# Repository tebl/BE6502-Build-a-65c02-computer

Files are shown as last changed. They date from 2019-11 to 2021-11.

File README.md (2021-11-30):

# BE6502 - Build a 6502 computer
[Ben Eater](https://eater.net/) has been a huge inspiration for many getting into building computers using basic electronic building blocks, his [videos](https://www.youtube.com/user/eaterbc) are truly excellent and it is no wonder he's often referred to as the Bob Ross of Breadboards! His latest project is [building a 6502 computer](https://eater.net/6502) on a breadboard, a video series that at this moment in time still has not concluded so this may not match whatever he does after part 7!

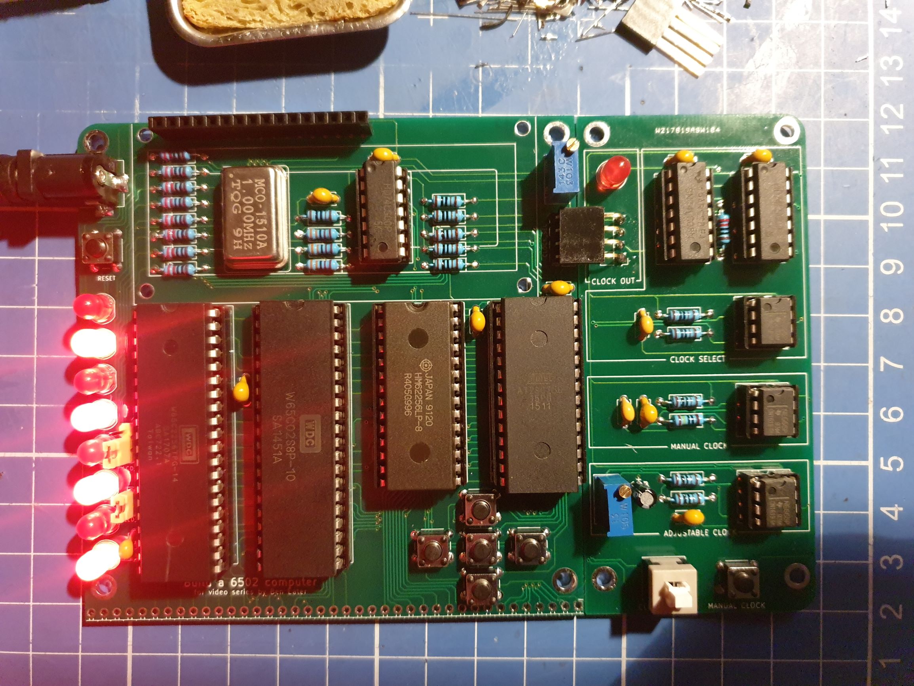
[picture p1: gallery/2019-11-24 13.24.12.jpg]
SBC and clock module


Personally, I am somewhat awful at getting things to work on breadboards - even when buying the good stuff from reputable electronics shops, so I usually just go directly to PCB instead. I've designed a few other amateur projects using the trusty old 6502-processor before, but this'll be the first one to be tackled with the more modern Western Designs CPU (W65C02) instead. His video series depends this specific brand of CPU, this is due to the way it is run using a slow and sometimes completely halted clock that wouldn't work the same on other brands. The older 6502 variants will more than likely loose their context, with the end result being a CPU doing unexpected things instead of running as the machine code would normally dictate. 

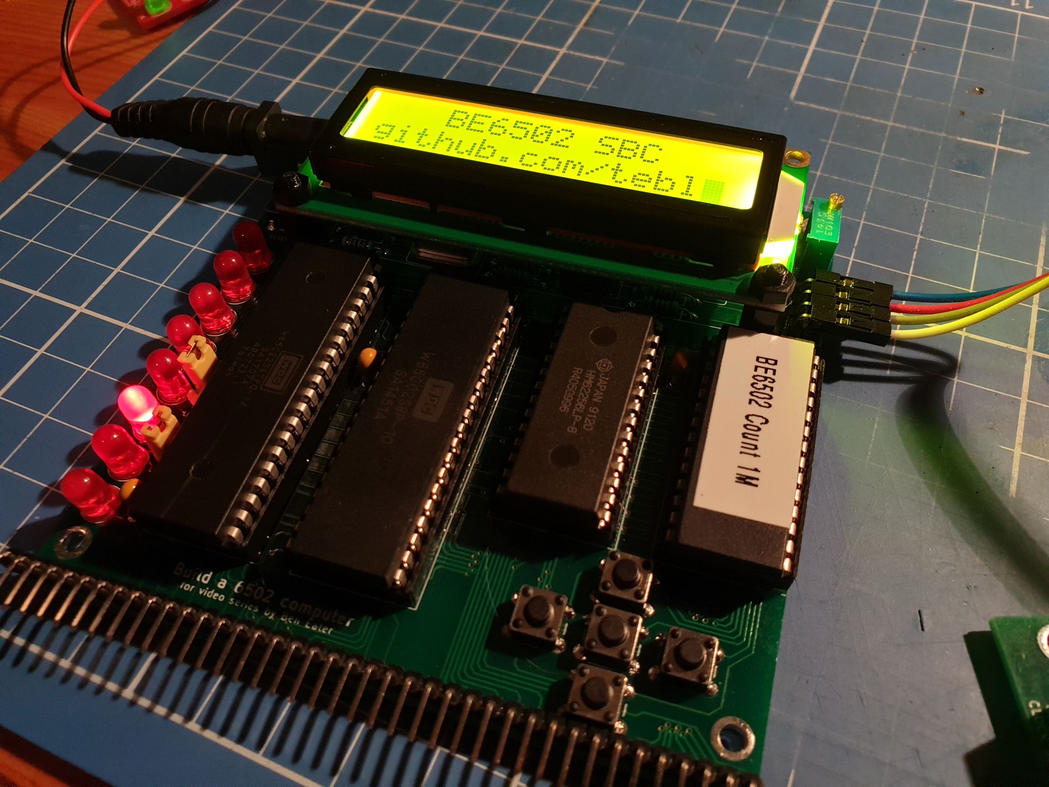
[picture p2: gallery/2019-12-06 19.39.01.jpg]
LCD mounted

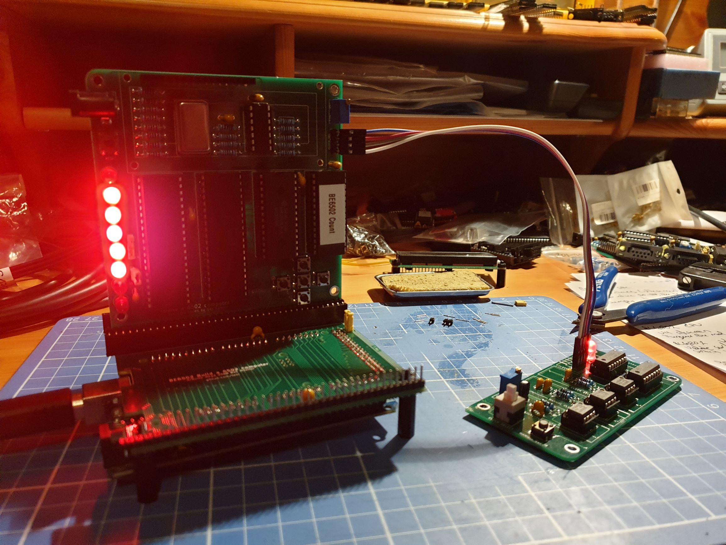
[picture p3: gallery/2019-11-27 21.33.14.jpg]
Computer with backplane


The BE6502 computer has a 39-pin backplane connector, like most of my other projects and these can be used to connect to an Arduino Mega as in the videos, a logic probe or even a separate larger backplane if you intend to build any more additional expansions for use with the computer. The picture above shows the SBC along with clock and Arduino Mega Shield. See *System modules* below for a listing of available modules, which are required at the various steps in the video series and any optional extras I felt like listing that would be compatible with the supplied boards.

Over time I may even add some short videos to show off the computer in action, but given that I have a voice suited for silent movies they'll probably just be videos of the computer blinking away by itself. As they become available, you'll find those on this [Youtube-playlist](https://www.youtube.com/playlist?list=PLOJSxpeHB9KTk9ptKCbEZnNEy9QRU02SS).

## Project status
The BE6502 computer is still in the prototyping stage and though I have studied the videos up to this point, at the time of writing that'd be everything up to and including part 7. See [TODO](https://github.com/tebl/BE6502/blob/master/TODO.md) for an overview of things I've yet to implement or want to change in the future!

Some of these details are likely to change as his original design by itself does not seem to reset reliably when using the 1 Mhz clock. At the moment I've got it fixed by using one of my own RC6502-modules in one of the backplane slots, details for this module can be found at https://github.com/tebl/RC6502-Apple-1-Replica/tree/master/RC6502%20Reset%20Circuit. If you'd like to build it up on a breadboard you can easily do that, I've installed pin headers as the front slot of my backplane to make it easier to do things like that. Alternatively you could program the Arduino Mega to do it for you!

### Errata
* [BE6502 SBC](https://github.com/tebl/BE6502/tree/master/BE6502%20SBC) revision A boards are missing a pull-up on the BE-pin - refer to this [picture](https://github.com/tebl/BE6502-Build-a-65c02-computer/raw/master/gallery/2020-02-16%2015.50.14-1.jpg) for a convenient spot to add one. This is resistor R18 in the current version of the schematic.
* [BE6502 Clock](https://github.com/tebl/BE6502-Build-a-65c02-computer/tree/master/BE6502%20Clock) module revision B had C8 shorted, refer to this [picture](https://github.com/tebl/BE6502-Build-a-65c02-computer/blob/master/gallery/Screenshot%202021-11-30%20194604.png) for how it should have looked (tracks have not been moved). In order to fix an existing PCB, cut off C8 and cut the trace directly below it. Installing new C8 (100nF) can be done on the back of the board, either across the short side of SW1 or between U2 pins 1 and 2.

## System modules
The following listed modules are available for use with the computer, where available I've also added an order URL to a shared project on PCBway for ease of ordering - click the module name to get more information as well as a complete list of components needed to build it (usually referred to as a BOM). Some modules have been marked with other computer names, these are other modules that I've found works directly and can be of interest when playing around with the BE6502-computer.

| Name | Video series, parts 1-7 | Future expansions | Order  |
| --- | --- | --- | --- |
| [Computer (SBC)](https://github.com/tebl/BE6502/tree/master/BE6502%20SBC) | required | | [PCBway](https://www.pcbway.com/project/shareproject/BE6502_Build_a_6502_computer__SBC_module_revision_A_.html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) |
| [Adjustable and manual clock](https://github.com/tebl/BE6502/tree/master/BE6502%20Clock) | required | | [PCBway](https://www.pcbway.com/project/shareproject/BE6502_Build_a_6502_computer__Clock_module_revision_A_.html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) |
| [Arduino Mega Shield and Backplane ](https://github.com/tebl/BE6502/tree/master/BE6502%20Mega%20Adapter) | required | | [PCBway](https://www.pcbway.com/project/shareproject/BE6502_Build_a_6502_computer__Arduino__and_backplane_module_.html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) |
| [RC6502 Backplane](https://github.com/tebl/RC6502-Apple-1-Replica/tree/master/RC6502%20Backplane) |  | optional | [PCBWay](https://www.pcbway.com/project/shareproject/RC6502_Apple_1_Replica__Backplane_module_revision_A_.html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) |
| [RC6502 Prototyping module](https://github.com/tebl/RC6502-Apple-1-Replica/tree/master/RC6502%20Prototyping) | | optional | [PCBWay](https://www.pcbway.com/project/shareproject/RC6502_Apple_1_Replica__Module_prototyping_board_.html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) |

If you would like to have a copy of one or more modules (usually 5$ per module), consider using the order links in order to support the development of these boards while doing so. You can alternatively zip up the contents of the export directory for each module and give that to your favourite PCB fabrication plant instead if you want to, but note that the files online here may be newer and have changes made to them that may not have been tested yet (the order link above will point to my last tested version).

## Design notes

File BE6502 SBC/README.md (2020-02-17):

# BE6502
[Ben Eater](https://eater.net/) has been a huge inspiration for many getting into building computers using basic electronic building blocks, his [videos](https://www.youtube.com/user/eaterbc) are truly excellent and it is no wonder he's often referred to as the Bob Ross of Breadboards! His latest project is [building a 6502 computer](https://eater.net/6502) on a breadboard, a video series that I'm sure will also inspire a lot of new users to the art of building stuff with the 6502! Check out the main [README](https://github.com/tebl/BE6502) for an overview of all the modules available to the BE6502 computer.

## Computer (SBC-module)
This module specifically contains all of the modules that makes the BE6502 an actual computer, it has the CPU, RAM, ROM and a way of interacting with the world using the VIA-chip. Also described as an SBC-module which means that it is a *Single Board Computer* though I'm certainly a fan of building more things around it, I just look at it has giving the computer more tricks that it can use to both entertain and educate us at the same time.

SBC and clock module

The picture above shows an assembled and currently running version of the SBC-module (without LCD attached), here I used a female pin header so that the clock module could be slotted directly into place alongside it. I did however change this to use dupont-cables later, this was because the boards separated too easily without having a plate to screw everything into at the moment

As you can see from the big shiny thing, I've also got the 1 Mhz oscillator installed as it is listed in Ben Eaters design though it is not connected by default so that the adjustable or manual clock can be used instead - to enable the 1 Mhz clock you'll need to install a jumper as shown below.

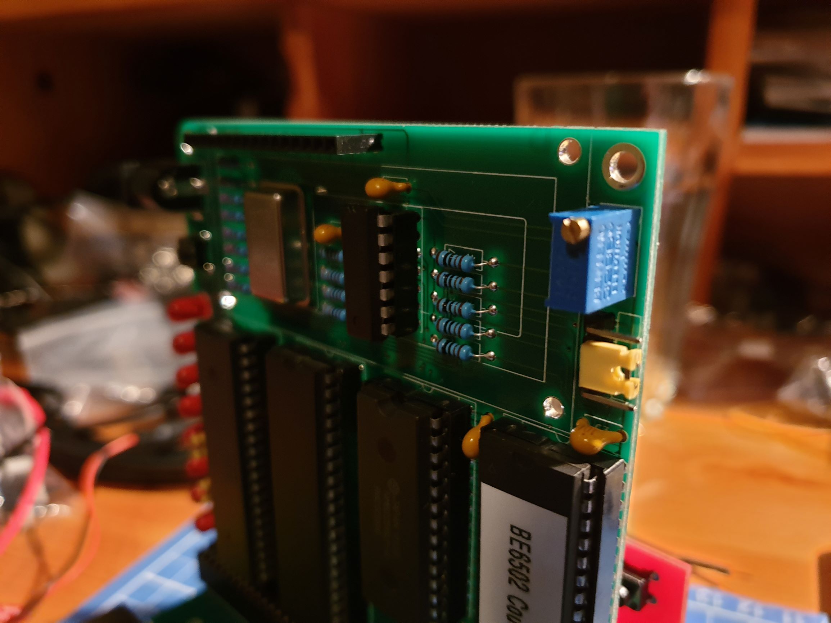
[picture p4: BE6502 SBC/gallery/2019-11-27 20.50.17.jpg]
1 Mhz


I did however have some issues running the CPU reliably at this speed, this is due to the reset circuit specified not being suitable for use at anything other than very low speeds. While we're probably waiting for part 8 of the video series to fix this issue, you can build one yourself on a breadboard with just about the same parts seen earlier in the series.

The hardware solution I'm using is a somewhat simplified version of the one at [RC6502 Reset Circuit](https://github.com/tebl/RC6502-Apple-1-Replica/tree/master/RC6502%20Reset%20Circuit), this is mainly by leaving out the oscillator (since we've already got one) and the 74LS74. For masters of the Commodore 64 the circuit will seem familiar, this is because it's the one originally used on its boards! Alternatively as a software solution, the Arduino Mega can also be used to perform this task - this is done by holding down the first switch (since revision B of the Mega Adapter) or by typing in reset via the serial interface.

## Jumpers
| Reference | Position | Description |
| --- | --- | --- |
| LCD_EN | 1-2 | Enable LCD |
| | 2-3 * | Disable LCD without physically removing it |
| LED_EN | o-o * | Jumpered to enable port B LEDs |
| CLOCK_SEL | 1 ** | VCC |
| | 2-3 ** | Jumper to enable 1 Mhz clock |
| | 4 ** | GND |

*) Marks the default jumpered positions when performing tasks associated with the first parts of the video series. Later, when the LCD is introduced, these will have to be changed.

**) CLOCK_SEL is also used as a connector when connecting the clock module, the pins are made to directly match the 4 positions on both modules. Pins 2-3 should only be jumpered when using 1Mhz clock, but you can also use pins 1 and 4 when powering other circuits. 

# Schematic
The supplied KiCad files should be sufficient as both a schematic and as a starting point for ordering PCBs (basically you could just zip the contents of the export folder and upload that on a fabrication site), the schematic is also available in [PDF-format](https://github.com/tebl/BE6502/raw/master/BE6502%20SBC/export/BE6502%20SBC.pdf) so that you can refer to it while troubleshooting. You could even print it out and hang it on your office wall, excellent conversation starter at any technology-oriented business worth working at (or so I keep telling myself)!

# BOM
This is the part list as it stands now, most should be easy to get a hold of from your local electronic component shop though you might have to consider other sources as that would depend on the quality of your local vendor.

Some vendors will have the same ICs in different form factors, the ones you want will often be specified as being in the form of a DIP/PDIP package. Usually you'll want sockets for each of the ICs as well, a bag of assorted sockets should be easily available without setting you back more than a couple bucks. With the sockets in place, you don't need to dread having to remove an IC later, this leads to easier fault finding and you can easily "borrow" them for other projects later! For the pin headers; you probably won't find the exact pin count as most are meant to be cut down to size, so just buy the 40 pin versions and snip off the parts you don't need!

| Reference | Item | Count |
| --- | --- | ----- |
| PCB | Fabricate yourself using Gerber files | 1 |
| C1-C6 | 100nF ceramic capacitor | 6 |
| D1-D8 | 5mm LED diode, green or red color | 8 |
| J1 | 39p right angle pin header | 1 |
| J2 | 4p right angle pin header | 1 |
| JP1 | 2p straight pin header | 1 |
| JP3 | 3p straight pin header | 1 |
| J3 | 2.1mm x 5.5mm barrel plug | 1 |
| JP1 | Single row, 2p straight pin header | 2 |
| R1-R3,R18* | 3k3 (3300) ohm resistor | 4 |
| R4-R9 | 1k ohm resistor | 6 |
| R10-R17 | 220 ohm resistor | 8 |
| U1 | W65C02 DIP-40 | 1 |
| U2 | 62256 Static RAM (DIP-28) | 1 |
| U3 | 28C256 EEPROM (DIP-28) | 1 |
| U4 | W65C22S DIP-40 | 1 |
| U5 | 74HC00 DIP | 1 |
| U6 | RC1602A, 16x2 character LCD | 1 |
| SW1-SW6 | Momentary push button | 6 |
| X1 | 1.000Mhz TTL Oscillator, (DIP-14) | 1 |
| | Jumpers for settings (CAP headers) | 3 |

*) R18 was added to SBC revision B boards as I had forgotten to add the pull-up for the BE-line, causing instability on the boards due to it floating around. Refer to this [picture](https://github.com/tebl/BE6502-Build-a-65c02-computer/raw/master/gallery/2020-02-16%2015.50.14-1.jpg) for a convenient spot to add it to revision A boards.

When constructing the board I recommend using 60/40 solder as the lead-free is more trouble than it's worth for hobby use, take your time with it and try to build up the board starting with the lowest components before moving on to the larger pieces. The LCD will be mounted on top of other components, so check that nothing shorts on the underside and unless you're 100% sure about the construction and my design - install some female header pins on it so that you can easily remove it while troubleshooting the circuit underneath!

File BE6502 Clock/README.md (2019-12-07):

[Ben Eater](https://eater.net/) has been a huge inspiration for many getting into building computers using basic electronic building blocks, his [videos](https://www.youtube.com/user/eaterbc) are truly excellent and it is no wonder he's often referred to as the Bob Ross of Breadboards! His latest project is [building a 6502 computer](https://eater.net/6502) on a breadboard, a video series that I'm sure will also inspire a lot of new users to the art of building stuff with the 6502! Check out the main [README](https://github.com/tebl/BE6502) for an overview of all the modules available to the BE6502 computer.

## Clock Module
Ben Eater has used the clock module from his 8 bit computer build with this project as well, this module is my implementation with only a few tweaks to the design. The main change apart from the whole PCB-design is that it has a slightly reduced chip-count, this was done by replacing the single used OR-gate with three NAND-gates instead (a little NAND-logic exercise).

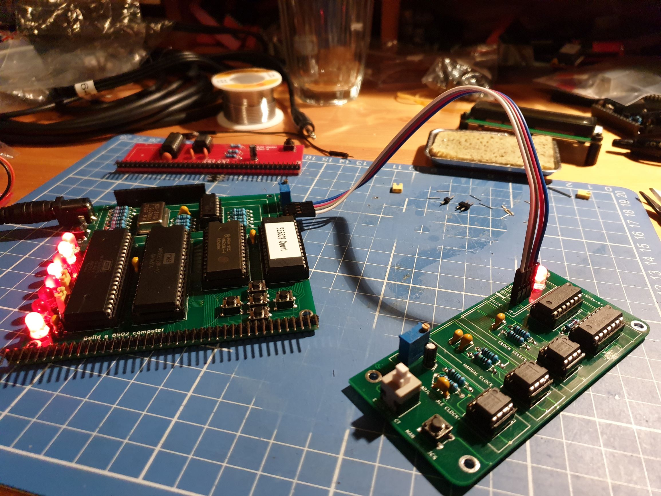
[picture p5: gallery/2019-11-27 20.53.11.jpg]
Running light without overbyte


Like the original breadboard version, you have a manual clock that allows you to clock in manual clock-pulses by pushing the button - the 555 in this case is used for debouncing (mechanical switches are not actually all that consistent). An adjustable slow clock is also available, here the 555 is used as a vibrator and will generate clock pulses with a frequency that is adjustable via the potentiometer. The final 555 allows for a clean transition between the two clocks so you can switch between the two without any erratic bahavior.

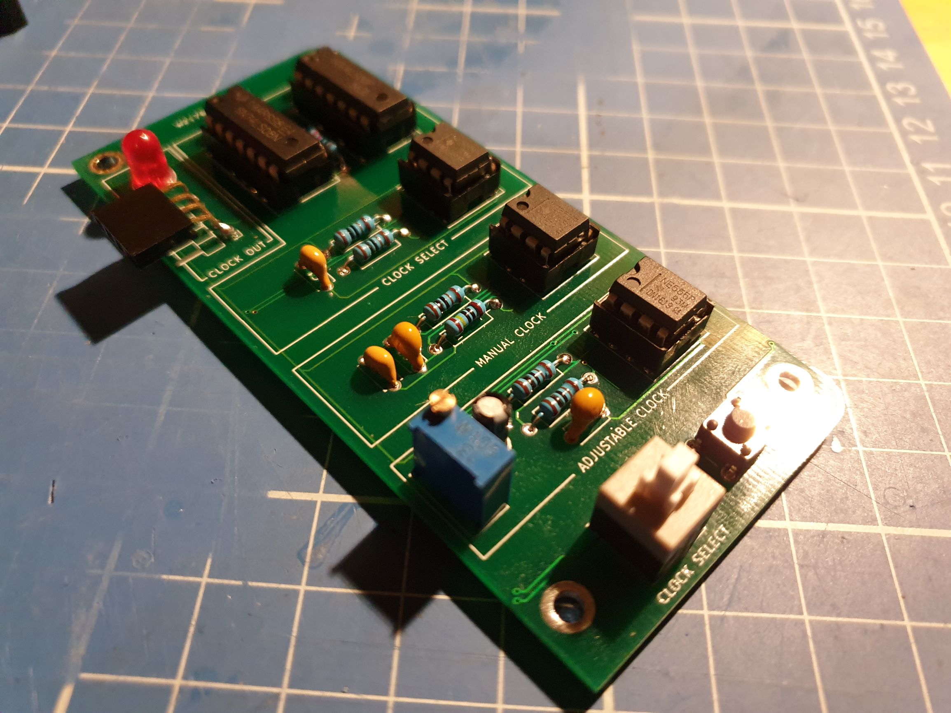
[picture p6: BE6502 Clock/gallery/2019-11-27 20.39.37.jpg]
Clock module


# Schematic
The supplied KiCad files should be sufficient as both a schematic and as a starting point for ordering PCBs (basically you could just zip the contents of the export folder and upload that on a fabrication site), the schematic is also available in [PDF-format](https://github.com/tebl/BE6502/raw/master/BE6502%20Clock/export/BE6502%20Clock.pdf) so that you can refer to it while troubleshooting. You could even print it out and hang it on your office wall, excellent conversation starter at any technology-oriented business worth working at (or so I keep telling myself)!

# BOM
This is the part list as it stands now, most should be easy to get a hold of from your local electronic component shop though you might have to consider other sources depending on the quality of yourlocal vendor.

Some vendors will have the same ICs in different form factors, the ones you want will often be specified as being in the form of a DIP/PDIP package. Usually you'll want sockets for each of the ICs as well, a bag of assorted sockets should be easily available without setting you back more than a couple bucks. With the sockets in place, you don't need to dread having to remove an IC later, this leads to easier fault finding and you can easily "borrow" them for other projects later! For the pin headers; if you can't find the exact pin count, just buy the longer 40 pin versions and snip off the parts you don't need.

| Reference | Item | Count |
| --- | --- | ----- |
| PCB | Fabricate yourself using Gerber files ([order](https://www.pcbway.com/project/shareproject/BE6502_Build_a_6502_computer__Clock_module_revision_A_.html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)) | 1 |
| C1.C2,C5 | 10nF ceramic capacitor | 3 |
| C3.C4,C7 | 100nF ceramic capacitor | 3 |
| C6 | 1uF electrolytic capacitor (2.5mm) | 1 |
| D1 | 5mm LED | 1 |
| R1-R3,R5-R6  | 1k ohm resistor | 5 |
| R4 | 1M ohm resistor | 1 |
| R7 | 220 ohm resistor | 1 |
| RV1 | Bourns 3296W 1M ohm potentiometer | 1 |
| U1-U3 | LM555, NE555 or equivalent (DIP-8) | 3 |
| U4 | 74HC00 (DIP-14) * | 1 |
| U5 | 74HC08 (DIP-14) * | 1 |
| SW1 | Momentary push button | 1 |
| SW2 | 6pin 8.5mm x 8.5mm latching switch | 1 |
| J1 | 4p straight pin header ** | 1 |

\*) HC-series chips have been specified as that is what Ben Eater used in his Build a 6502 computer series, but can also be HCT-series depending on what you have access to. For more information on the various logic families, see the [6502 Primer on the topic of logic families](http://wilsonminesco.com/6502primer/LogicFamilies.html).

\**) You can use a female right-angle pin header and match it directly to the BE6502 SBC with some careful adjustments, but I recommend using some female to female dupont leads instead as the connector is a bit too loose when not mounting boards on a backing plate.

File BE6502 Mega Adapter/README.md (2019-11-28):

[Ben Eater](https://eater.net/) has been a huge inspiration for many getting into building computers using basic electronic building blocks, his [videos](https://www.youtube.com/user/eaterbc) are truly excellent and it is no wonder he's often referred to as the Bob Ross of Breadboards! His latest project is [building a 6502 computer](https://eater.net/6502) on a breadboard, a video series that I'm sure will also inspire a lot of new users to the art of building stuff with the 6502! Check out the main [README](https://github.com/tebl/BE6502) for an overview of all the modules available to the BE6502 computer.

## Arduino Mega 2560-shield and Backplane
During the initial videos, Ben Eater shows how an Arduino Mega 2560 can be used when debugging or even seeking to understand how a 6502 computer works. This is done by connecting up the address/data busses as well as some of the control signals (R/W and the clock), the values are then printed every clock pulse.

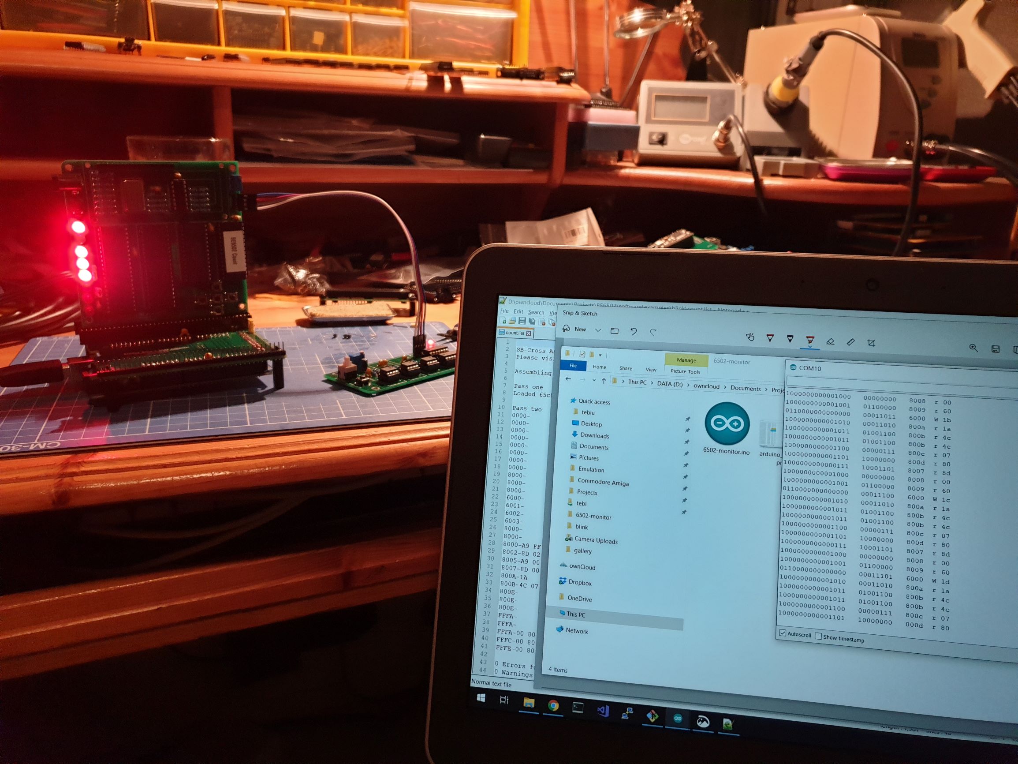
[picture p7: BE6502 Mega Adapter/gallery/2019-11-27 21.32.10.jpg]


That's a lot of wires and I don't have that kind of patience, so I designed it as an Arduino Mega 2560-shield that doubles up as a two (or three) slot backplane. You plug the SBC-module into one of them, then you can use the other for whatever expansion module you want to try out with the system. The third and outer set of pins can be installed as slot in the same manner, but I opted to install straight header pins here instead - that way I can use some female to male dupont wires and easily run them as needed over to a breadboard.

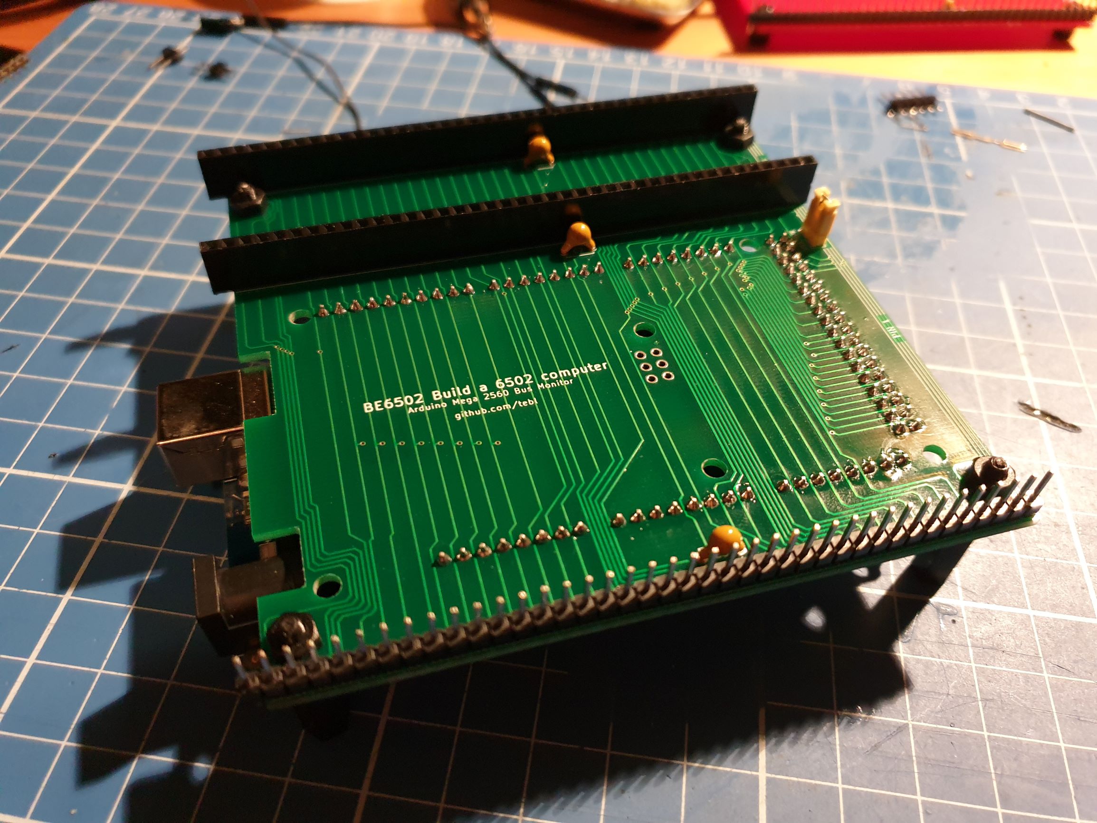
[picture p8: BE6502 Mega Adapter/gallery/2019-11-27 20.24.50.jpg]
Backplane

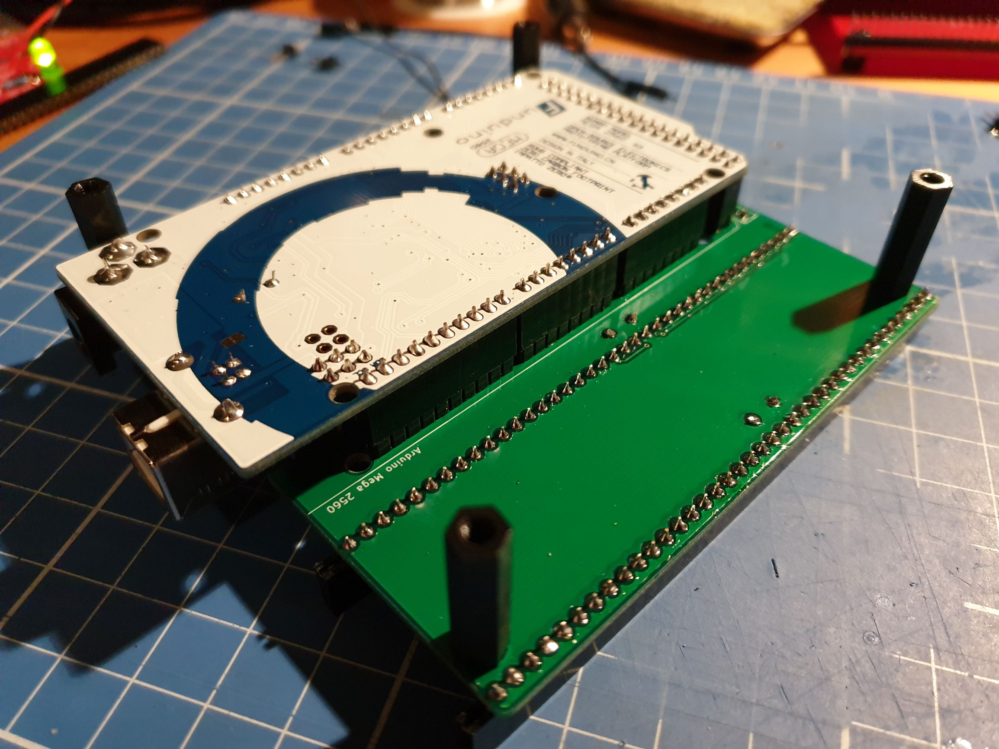
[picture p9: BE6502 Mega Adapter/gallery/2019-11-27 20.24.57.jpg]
Arduino attached


I've adapted the Arduino sketch created by Ben Eater, mostly I've just changed a few minor things to have them just like I would like them to be - I've also added all of the other BE6502-backplane signals available since they have all been mapped over to the Arduino Mega 2560. What's particularly awesome about that is that you can program the Arduino Mega to manually control the signalling without the SBC-module present, meaning that you now have the added ability to test out expansion module logic step by step.

For more information about using the sketch to analyze the computer while it is running as well as a few annotations that should help make the data streaming into the console more understandable, see [6502-monitor](https://github.com/tebl/BE6502/tree/master/software/arduino/6502-monitor) within the software-section of the project. Arduino console with the reset vector highlighted in yellow can be seen below as an example of output.

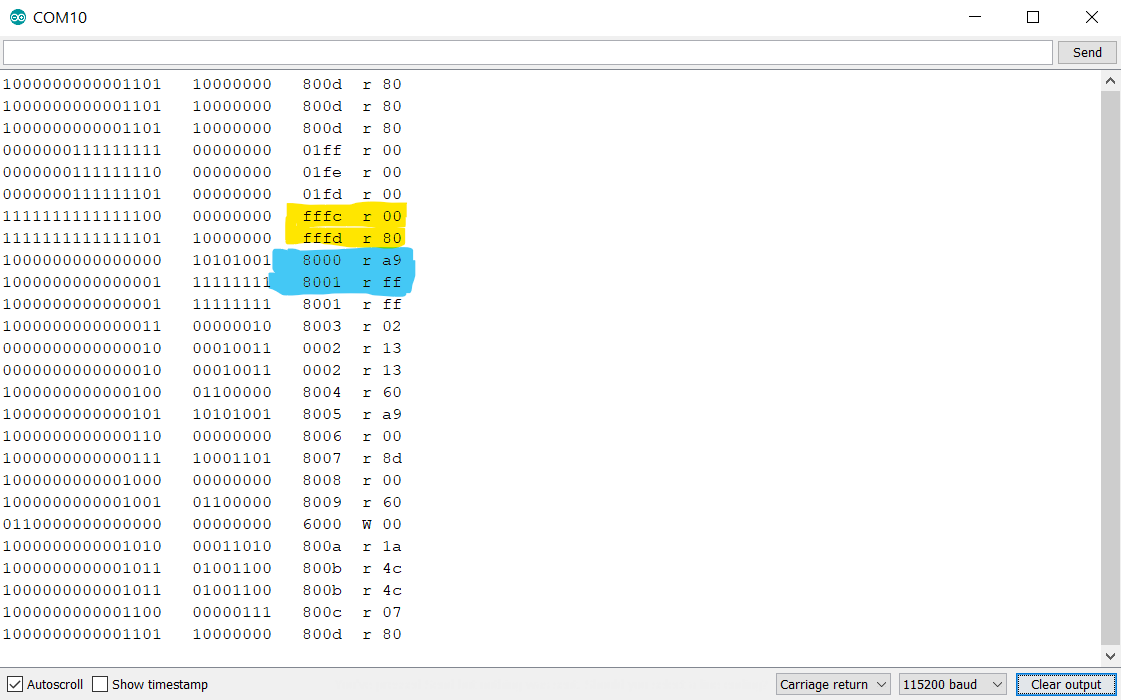
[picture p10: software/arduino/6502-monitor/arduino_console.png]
Arduino console


## Jumpers
| Reference | Position | Description |
| --- | --- | --- |
| USB_PWR | o-o * | Link to power from/to Arduino Mega 2560 |

*) This is the default position and will allow the Arduino Mega 2560 to be powered at all times, so do not be alarmed if the module wakes up when power is applied to the BE6502 SBC barrel connector - remove jumper to keep it off if you're not running any sketches that work without a computer connected to the module.

# Schematic
The supplied KiCad files should be sufficient as both a schematic and as a starting point for ordering PCBs (basically you could just zip the contents of the export folder and upload that on a fabrication site), the schematic is also available in [PDF-format](https://github.com/tebl/BE6502/raw/master/BE6502%20Mega%20Adapter/export/BE6502%20Mega%20Adapter.pdf) so that you can refer to it while troubleshooting. You could even print it out and hang it on your office wall, excellent conversation starter at any technology-oriented business worth working at (or so I keep telling myself)!

# BOM
This is the part list as it stands now, most should be easy to get a hold of from your local electronic component shop though you might have to consider other sources depending on the quality of yourlocal vendor.

Some vendors will have the same ICs in different form factors, the ones you want will often be specified as being in the form of a DIP/PDIP package. Usually you'll want sockets for each of the ICs as well, a bag of assorted sockets should be easily available without setting you back more than a couple bucks. With the sockets in place, you don't need to dread having to remove an IC later, this leads to easier fault finding and you can easily "borrow" them for other projects later!

| Reference | Item | Count |
| --- | --- | ----- |
| PCB | Fabricate yourself using Gerber files ([order](https://www.pcbway.com/project/shareproject/BE6502_Build_a_6502_computer__Arduino__and_backplane_module_.html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)) | 1 |
| C1.C2,C3 | 100nF ceramic capacitor | 3 |
| J1 | 39p straight pin header * | 1 |
| J2-J3 | 39p female pin header * | 2 |
| JP1 | 2p straight pin header | 1 |
| | Jumpers for settings (CAP headers) | 1 |
| XA1 | Arduino pin headers ** | |

*) You won't find the exact pin count for these, so the easiest is to use the 40 pin versions instead - either leave the last pin hangig across where pin 40 should have been or snip it off!

**) I'm not going to list these separatately, but you'll need some single and double row pin headers that you can cut down to size and solder to the board. Usually I insert them into the Mega itself, position the board on top and then tack each one in place temporarily to get the alignment correct. Remove the Arduino Mega 2560 board, then finally solder the pin headers into place.

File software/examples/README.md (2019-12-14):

# Introduction
This directory contains a set of examples that've been made in order to test out the various parts of the BE6502-computer, the numbering scheme is mostly to put them into order from the simplest to the slightly less simple in terms of code. Along the way I've been attempting to learn some simple 6502 assembly programming myself, so there is every possibility that far more sophisticated solutions to the same problems exist somewhere out there.

The following examples of code developed for the system are available, they have been numbered according to complexity - hopefully they'll end up building towards something more substantial though they should be sufficient to show off the various features of the system. There may be more code examples hanging around in the various sub-directories, but either I didn't finish them - or I just forgot to add them to the list! Given that there is a slow clock available for the system, I've not taken the time or sought to increase the complexity of each one by adding the additional complexity needed to sufficiently slow down a 1Mhz system in order for the LEDs to function as expected.

| Number | Name | Description | Slow clock | 1 Mhz | URL |
| --- | --- | --- | --- | --- | --- |
| 001 | noblink | Blink an alternating pattern on LEDs | X | | [DIR](https://github.com/tebl/BE6502/tree/master/software/examples/001%20-%20Blink)
| | count | Count up in binary from $00 to $FF | X | |
| | count_mhz | Same as above, but can run at 1Mhz | | X |
| 002 | echo | Show switch status on the LEDs directly | X | X | [DIR](https://github.com/tebl/BE6502/tree/master/software/examples/002%20-%20Echo)
| 003 | debounce | Read switches and perform code for each of them | X | | [DIR](https://github.com/tebl/BE6502/tree/master/software/examples/003%20-%20Debounce)
| 004 | hello_lcd | Initialize LCD and output a string to it | X | | [DIR](https://github.com/tebl/BE6502/tree/master/software/examples/004%20-%20Hello%20LCD) [README](https://github.com/tebl/BE6502/blob/master/software/examples/004%20-%20Hello%20LCD/README.md)
| 005 | scratchpad  | Use keys to move around LCD and middle button to put an 'X' there | X | X | [DIR](https://github.com/tebl/BE6502/tree/master/software/examples/005%20-%20Namebadge)
| | namebadge | Use keys to move, middle to edit then up/down to change | X | X |

For some of the examples I've included more than one version, usually they build upon the previous to make something slightly more impressive (or not, depending on familiarity with writing assembly code). Take a look at the README file that comes with the example, if I've included one, for more of the specifics. Files that belong together should have consistent naming according to what is described above, there are several files with the same name though with differing extensions - the following table is a short description of what you'll find inside:

| Extension | Description |
| --- | --- |
| *.asm* | Assembly code for the program, this is where you fix my bugs.
| *.hex* | Intel HEX-file generated by the assembler, this is what you burn onto an EEPROM using an EEPROM-burner
| *.list* | This is the output from the assembler, very useful when debugging code as it shows the bytes the program was assembled into as well as the code (including comments). Read this when studying how a program works

## Assembling things
The 6502-CPU processes machine code and not assembly code, but while the latter may not be the easiest of languages to understand I assure you it's supposed to be more readable to us humans and not the machine. Generally though it's just a simple step above machine code, which is why each of the statements translate line by line to a single machine code instruction at a time. In order to take the *human-readable assembly code*  and translate it into something the computer can use, we'll need something called an *assembler*.

While Ben Eater opted for one called vasm in his videos, I chose [SB-Assembler 3](https://www.sbprojects.net/sbasm/) instead - it's bing actively updated and since I already had Python installed it was merely a matter of dropping some files into a folder somewhere.

One thing that confused the heck out of me at the start of all this, probably a couple of weeks ago (give or take) - is that there isn't a single defined *assembly-language* as compared to something like Python, Java etc. Mostly the assemblers seem to agree on the resulting machine code though some may include optimizations others do not, everything outside of that however - may have slight differences so code written for one assembler will often not work directly with a different assembler. Back in the day everyone had the same datasheets for the processor, but assemblers and such were usually expensive and proprietary stuff that you weren't even supposed to share the documentation for.

Sometime later, we of course got the Internet and somehow we started to agree on the basics of things thought the software and dialects remained. One common task when starting to learn a new assembler, therefore is to take some existing assembly code that you know work and start converting that to your favourite assemblers dialect. 

Each project comes with their own little batch-file to make things easier on myself, but there isn't really a need for them - if you do end up using them, then you need to ensure that SB-Assembler 3 has been included in the system PATH environment variable. A file can be manually assembled into machine code by running something like the following:
```
sbasm.py monitor.asm
```

## Burning things
If you do not wish to alter the code, then the Intel HEX file should be suitable for flashing onto a 28C256 EEPROM using your favourite brand of EEPROM burner (I use the MinoPRO TL866CS, it's the only one I've needed so far). Start by using *Select IC*, search for 28C256 and selecting the suitable type as according to the writing on the chips you ordered. Then use *Open file*, browse into the example you want to load onto the chip - look for the file with the *.hex*-extension and select that - just accept the standard option for the next. Finally, use the option *Program \(P\)* from the *Device \(D\)* menu.

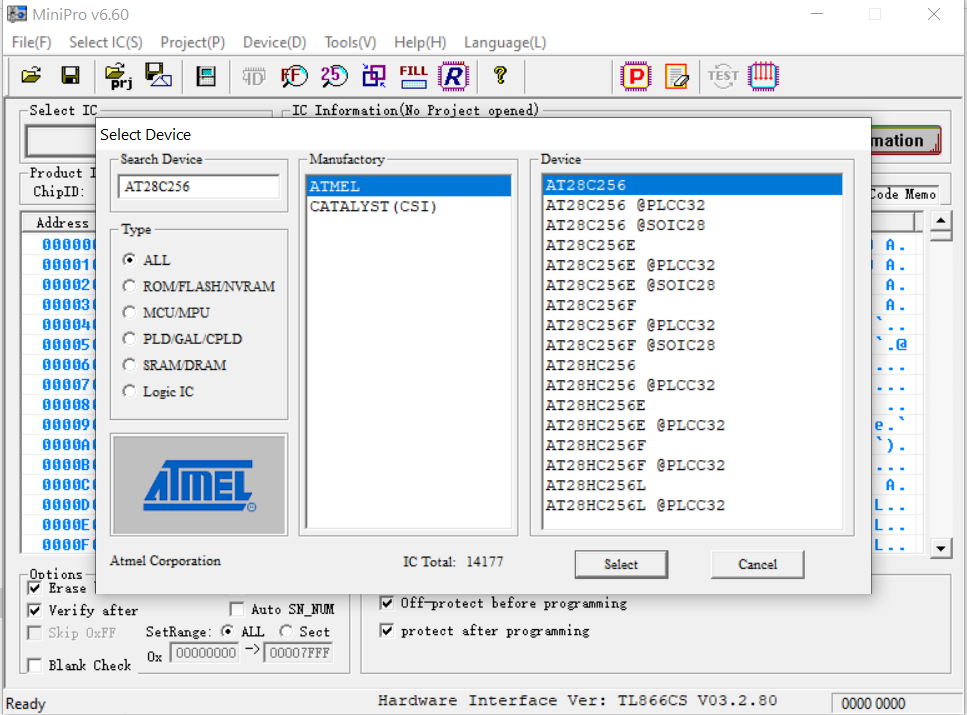
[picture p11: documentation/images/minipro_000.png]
MiniPro Image 000

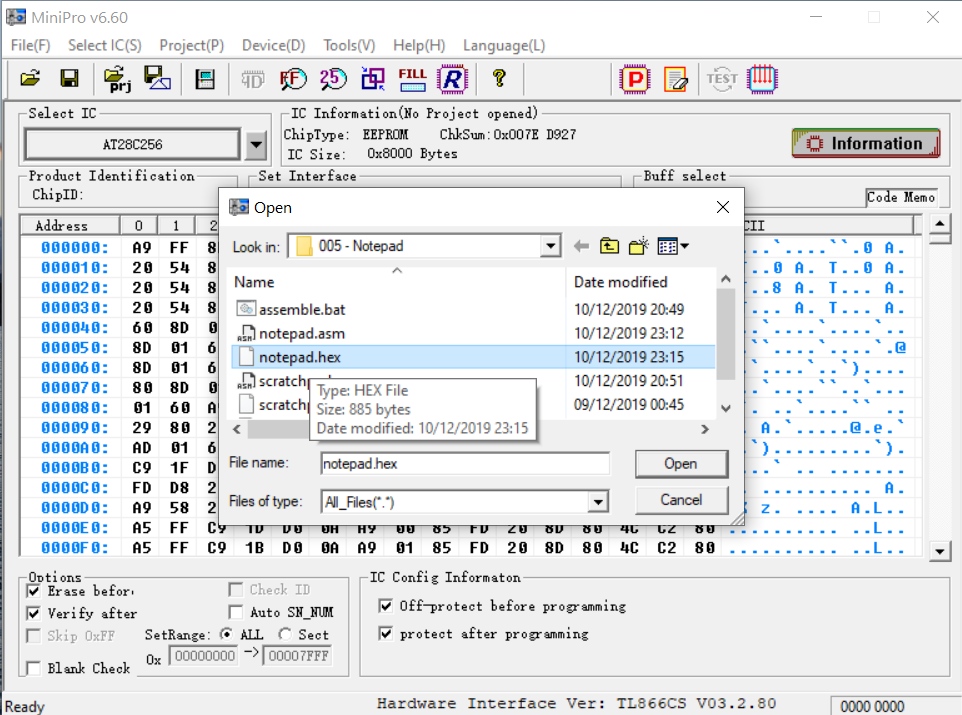
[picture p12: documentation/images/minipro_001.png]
MiniPro Image 001

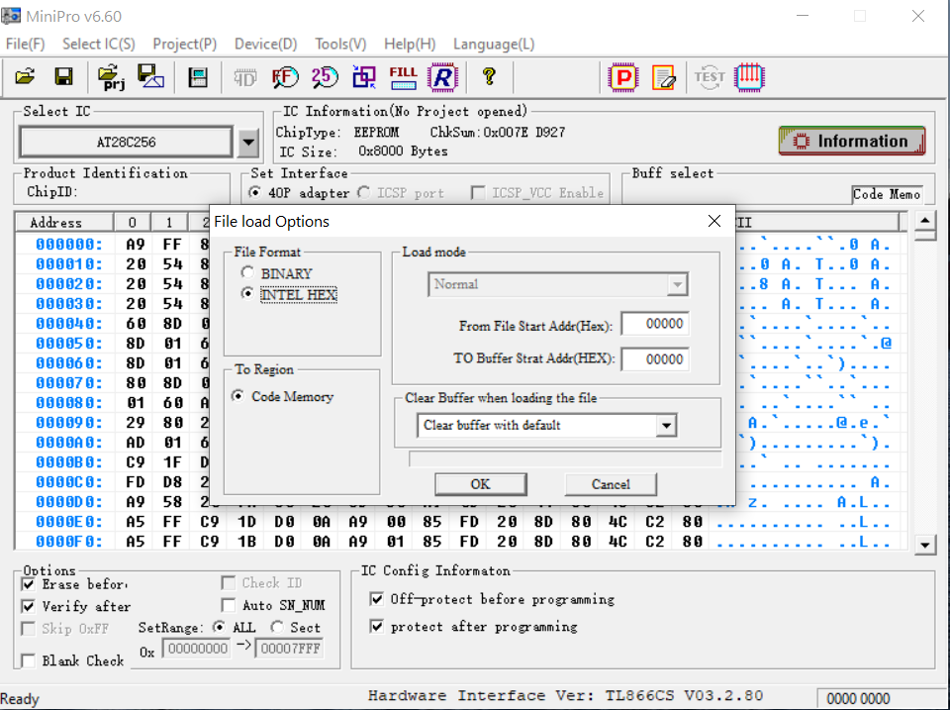
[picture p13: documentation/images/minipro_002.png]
MiniPro Image 002


Insert the chip into the EEPROM burner according to the illustration shown on screen, hit *Program* and watch it burn the cheap beyond recognition (just kidding). Watch for errors, if you get any - doublecheck that you selected the correct chip type, alternatively pop another one into the burner and see if that works instead (I buy them in 10-packs from China, there's usually one or two that's dead so it's always good to have extras).

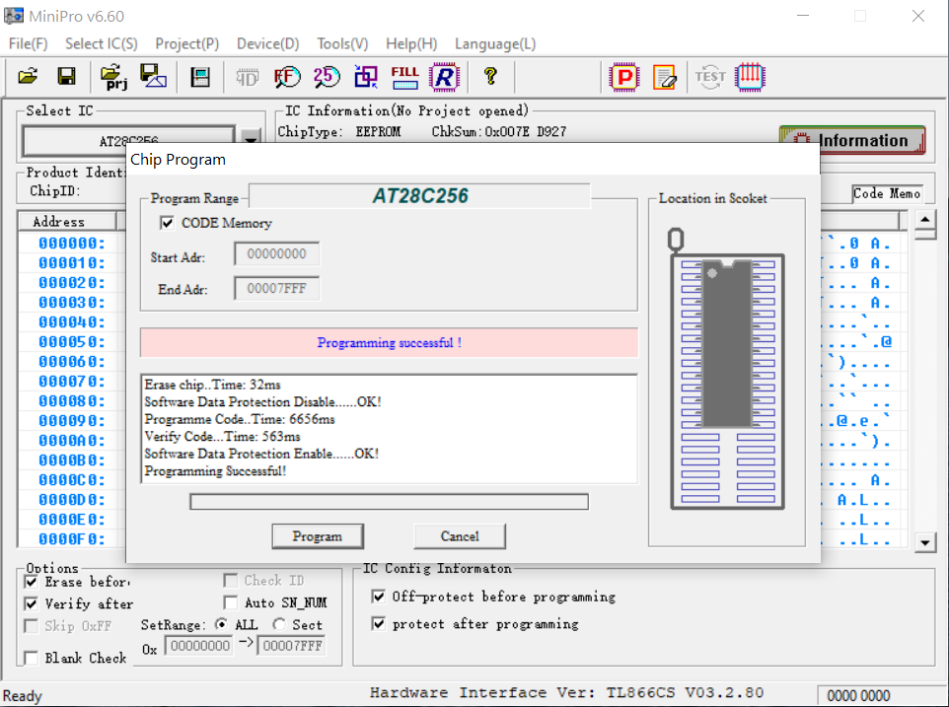
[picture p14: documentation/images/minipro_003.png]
MiniPro Image 003


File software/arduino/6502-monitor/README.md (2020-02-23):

# 6502 Bus Monitor
My first version of this sketch was essentially identical to the one Ben Eater provided for his *Build a 6502 computer* video series, so for the core features he's still the one to credit for all of this. Over time I've added quite a lot of features to the sketch in order to further enhance it, among the features added is a command-based serial interface. ability to have Arduino Mega replace the slow clock as well as using the special *BUS Enable* feature of the w65c02 processor to temporarily halt it and allow us to control the peripherals directly in its absence.

The sketch attempts to increase readability by using ANSI colour commands, but if this is not supported by your terminal software then you might end up with a lot of extra wierd characters in the output; if you do, try giving the command *ansi off* to turn them temporarily off. If this fixes your problem you may consider turning them off permanently by editing the ".ino"-file though I'd recommend that you instead install a better terminal program and use that instead (I recommend using Tera Term).

When you get so far that you want to move data to the computer by pasting the contents of your HEX-files into the terminal window, then you'll need to look into adding some time delays to the data sent out to the board - this is needed because the Arduino doesn't include any form of flow control, but your computer running at several Ghz will easily and quickly overrun the measly 16Mhz processor available to the Arduino. Tera Term makes that easy to do, which is why I recommend it.

## Arduino settings
I'm using a Funduino-branded Arduino Mega 2560 with the sketch, but for my own reference as there's starting to be a lot of boards and versions out there - these are the board settings I'm using within the Arduino software:

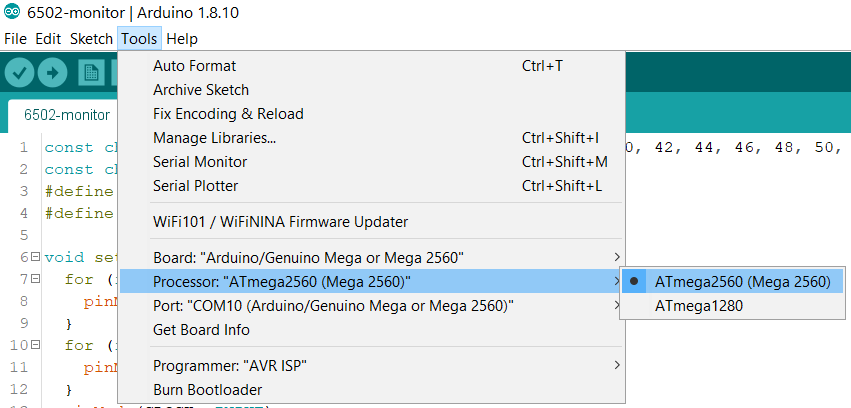
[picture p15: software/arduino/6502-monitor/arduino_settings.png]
Arduino settings


## Using the sketch
The usage of the sketch is expertly explained in Ben Eaters video series, in particular [part 2](https://www.youtube.com/watch?v=yl8vPW5hydQ) of the series. As part of my own notes, though it may certainly be of interest to anyone else viewing this page is the image shown below - it attempts to correlate what the computer sees to what you'll see within the Arduino-console.

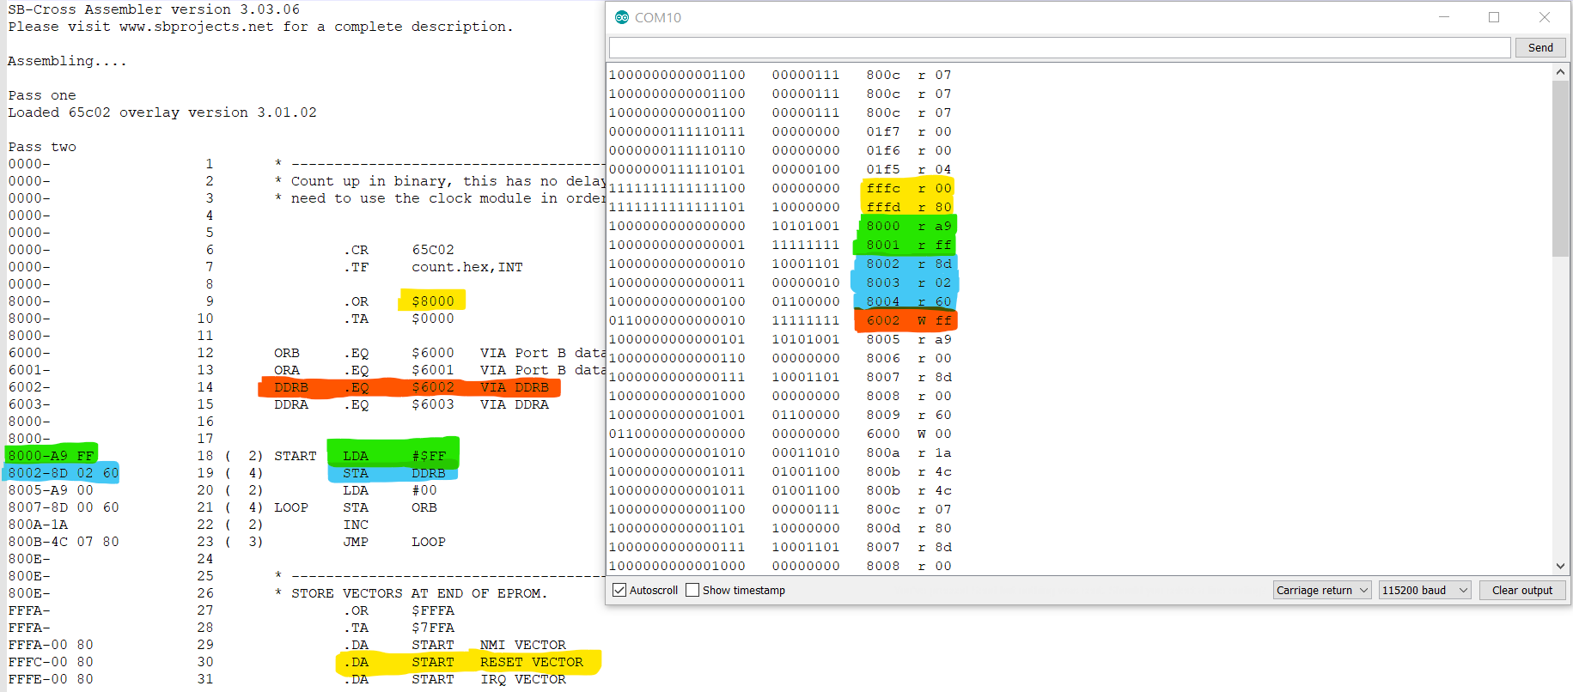
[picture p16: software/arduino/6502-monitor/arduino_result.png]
Sketch results


Here the initial steps of the of the CPU initializing and then reading the initialization vector has been highlighted in yellow, then the three first instructions and the way it relates to the assembled version of my [count](https://github.com/tebl/BE6502/tree/master/software/examples/001%20-%20Blink)-assembly program can be seen (assembled using [SB-Assembler 3](https://www.sbprojects.net/sbasm/)). The remaining colours show how the various parts relate to each other.

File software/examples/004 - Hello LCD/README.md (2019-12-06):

# Hello LCD
The BE6502 can be used with most common HD44780-compatible parralell LCD displays, these are commonly listed as LCD 2004 (20 characters wide, 4 lines) or LCD 1602 (16 characters wide, 2 lines). The footprint on the PCB as well as the examples in this folder have been developed for the latter of the displays, the LCD 1602. The former and physically larger display will also work without any changes to the code, but you'll only see two of the lines being used.

I found the page [elm-chan.org/docs/lcd/hd44780_e.html](http://elm-chan.org/docs/lcd/hd44780_e.html) to be very helpful when developing the code for the example code found in this directory. One of the things that initially threw me when working on it is that the display physically has a line lenght of 16-characters, but logically it has a width of 20-characters so if you're outputting text directly to it you'll see some of hidden between the lines. This page also shows the steps needed to properly initialize the display from an unknown state at powering up the computer.

The code does not include the needed delays needed to allow the display enough time to respond during initial power-up, it actually needs something like 160ms between each command. Therefore it should be run using the slow clock module.

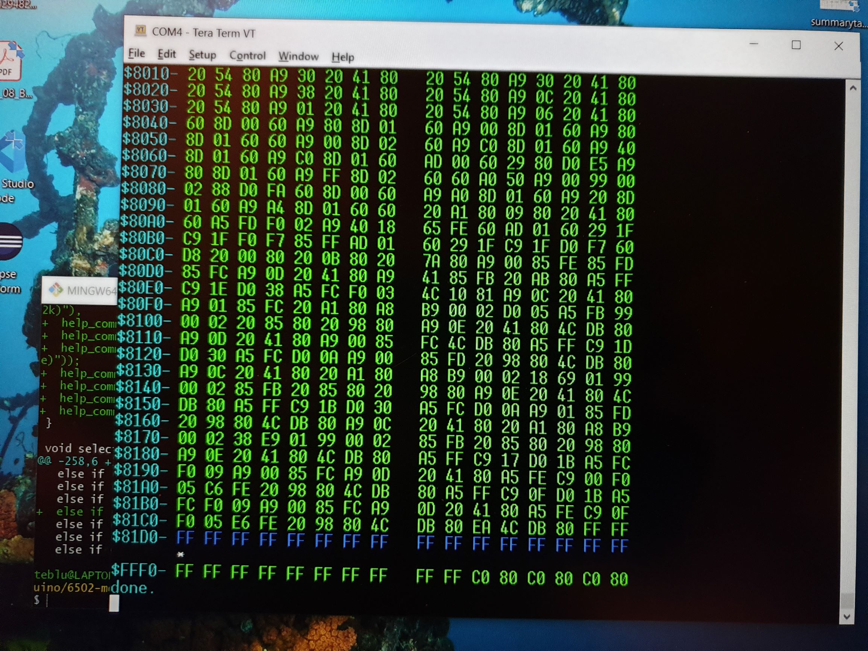
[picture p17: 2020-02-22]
gallery/2020-02-22 20.33.38.jpg

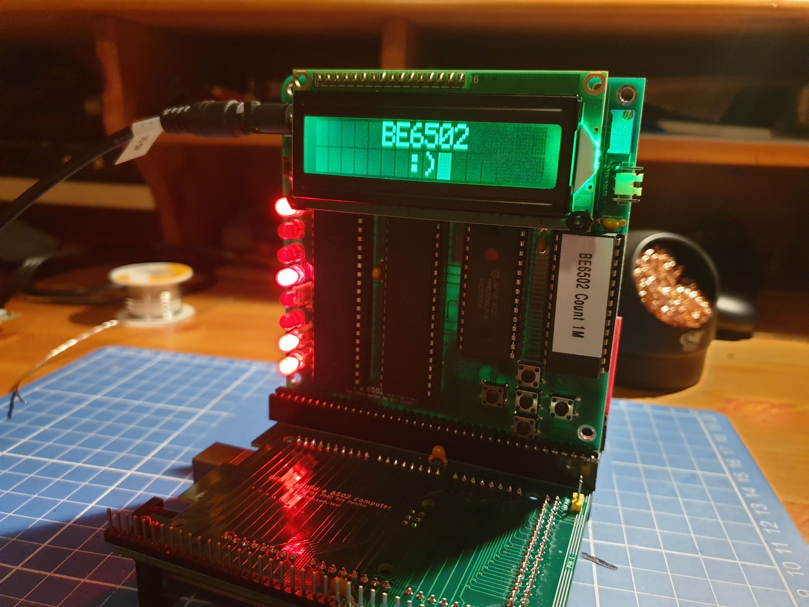
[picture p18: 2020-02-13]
gallery/2020-01-19 00.14.13.jpg

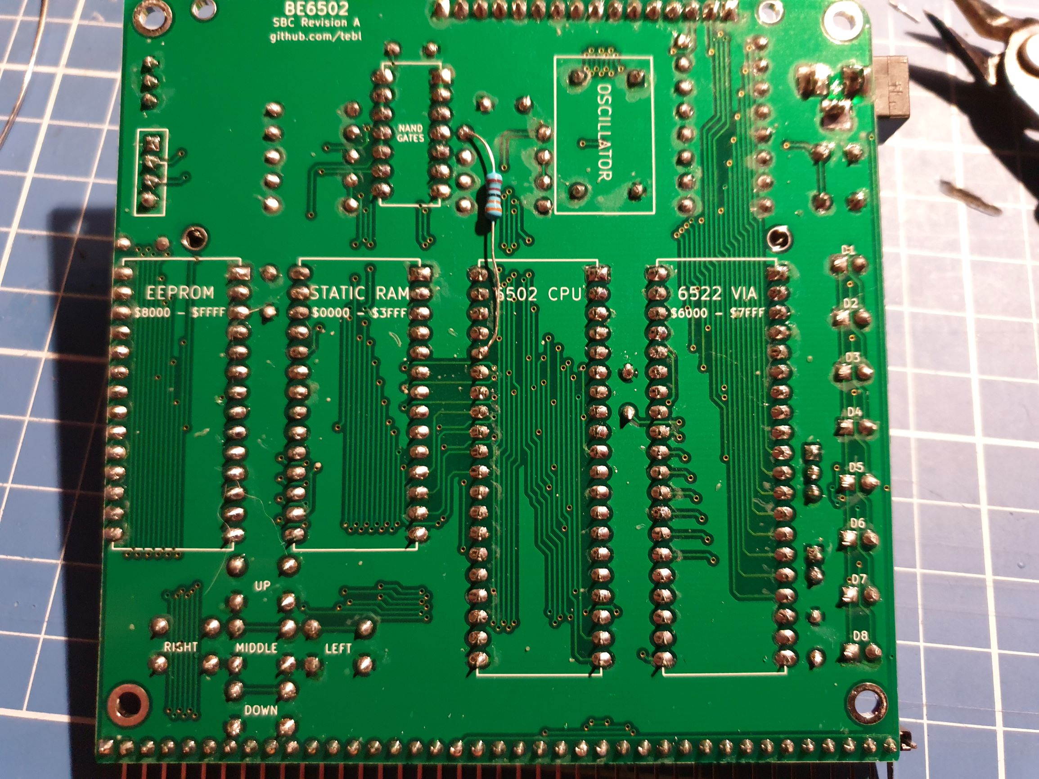
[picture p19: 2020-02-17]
gallery/2020-02-16 15.50.14-1.jpg

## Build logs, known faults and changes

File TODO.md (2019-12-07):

# TODO
There is always things to do, but not enough time for everything. I've tried to maintain a list of outstanding tasks below, organized by module.

## Clock module
- Manual clock is somewhat flaky, but it is the same as the one used in the videos so I assume this is part of the design. Will probably make some alterations to it when the video series have been completed.

## SBC
- Make necessary changes when final video drops.
- Reset circuit as specified in the video series is insufficient for running at reasonable speeds, ie. anything other than using the slow clock. This'll be redesigned if not part of final design when final videos are released.

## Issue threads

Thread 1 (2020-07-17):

Discharge Pin 7 of 555 timer manual clock not following schematic

bgulotta, 2020-07-17:
I believe pin 7 of the manual clock circuit is not following the schematic and going through the 100nF capacitor to ground. Thanks for the great pcbs.

bgulotta, 2020-07-17:
Disregard. I tested the traces with my multimeter and everything checks out. ;)

Closed 2020-07-17.

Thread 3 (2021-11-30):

C8 Capacitor Clock Module

davrad3, 2021-11-30:
Hello,
thank you for this amazing project.
I had the pcb produced and now I am wondering why the 4 pins of SW1 are connected to each other and why the capacitor C8 is connected to GND with both pins.
Thank you so much

tebl, 2021-11-30:
This appears to have been one of my mistakes, sorry about that. I've added some details to the errata section of the README, can you check that out and see if that fixes the issue. Cutting the track under C8 should stop all of the pins under SW1 from appearing shorted.

https://github.com/tebl/BE6502-Build-a-65c02-computer#errata

davrad3, 2021-11-30:
Thank you very much!

Closed 2022-02-20.

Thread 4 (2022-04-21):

Links to order with PCBway are only Version A

arminth, 2022-04-21:
Please update the files on PCBway to the latest versions. I ordered and received A Versions only. Not a big deal with the SBC or clockmodule, but the arduino shield is missing the userbuttons and LED which makes using the monitorprogram not so easy.

Other than that thanks a lot for your work! It works perfectly!
Cheers
Armin

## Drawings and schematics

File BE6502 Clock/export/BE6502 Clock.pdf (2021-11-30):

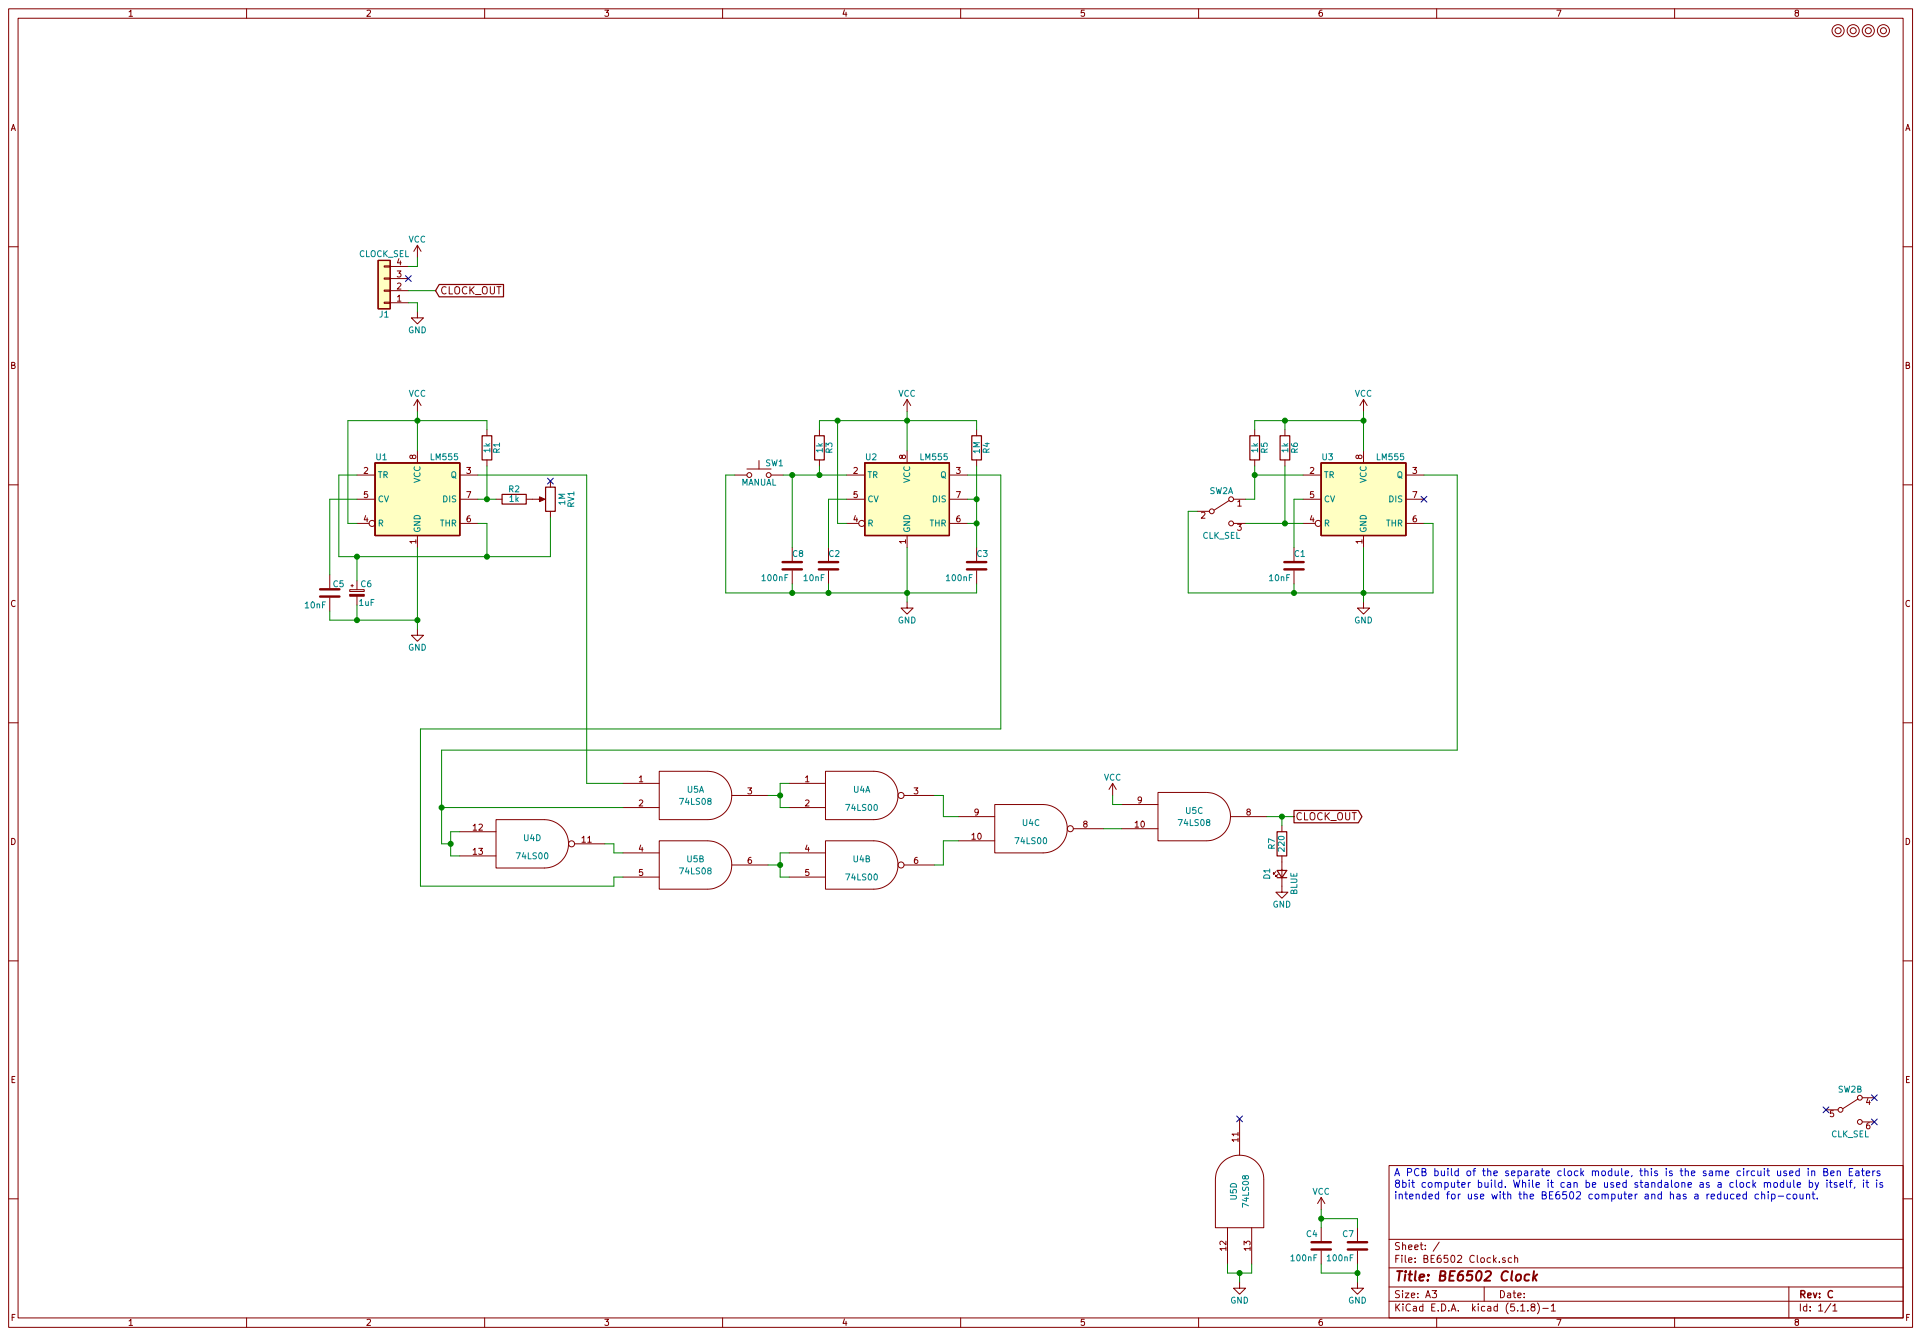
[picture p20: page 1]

A PCB build of the separate clock module, this is the same circuit used in Ben Eaters
8bit computer build. While it can be used standalone as a clock module by itself, it is
intended for use with the BE6502 computer and has a reduced chip-count.

File: BE6502 Clock.sch Sheet: / C4

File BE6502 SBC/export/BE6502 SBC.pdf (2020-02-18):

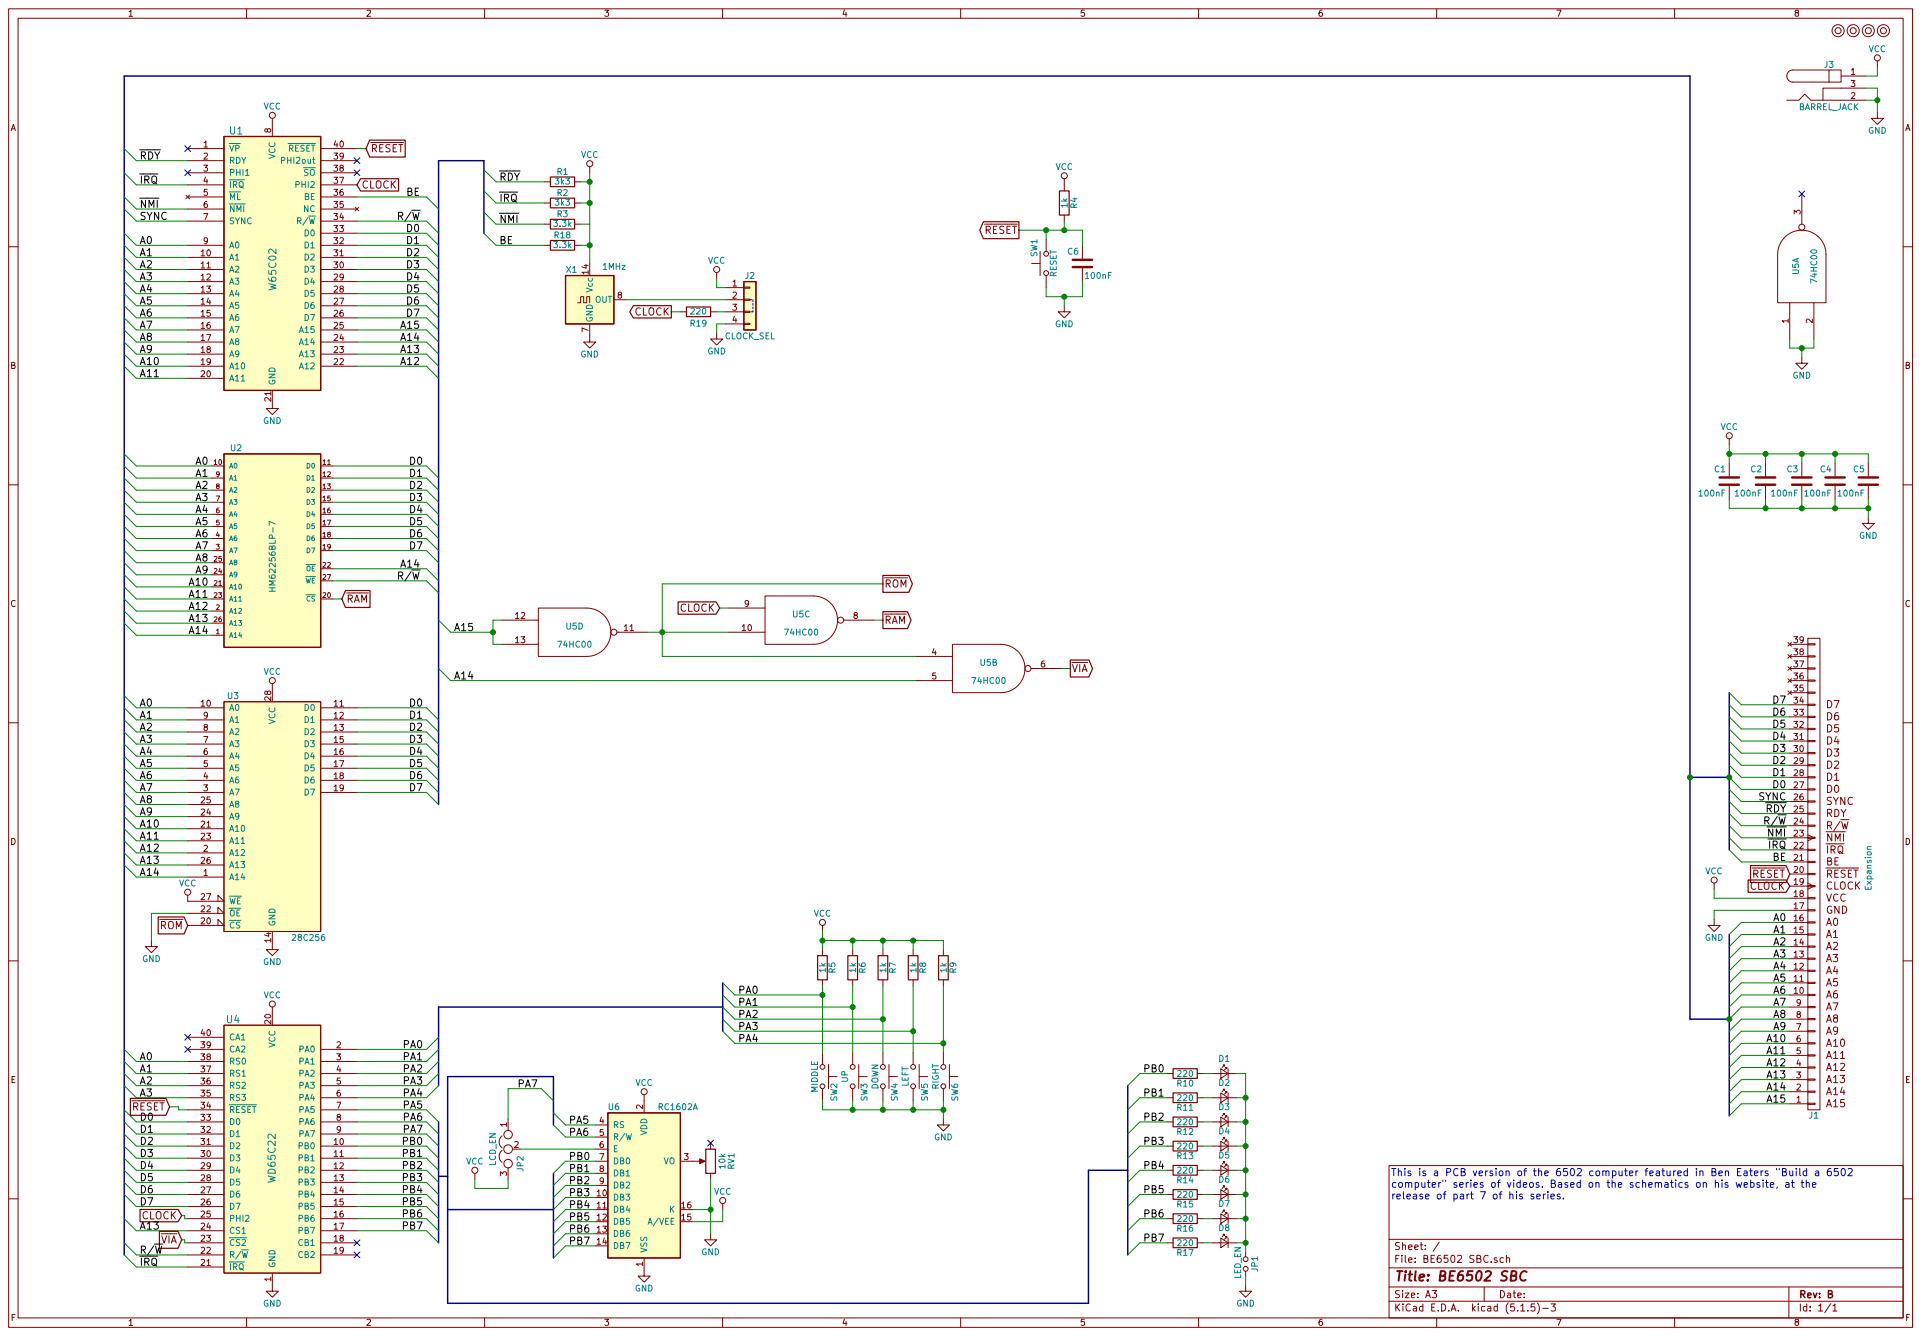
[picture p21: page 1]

23
IRQ 22
21

File: BE6502 SBC.sch Sheet: / GND

computer" series of videos. Based on the schematics on his website, at the
release of part 7 of his series.

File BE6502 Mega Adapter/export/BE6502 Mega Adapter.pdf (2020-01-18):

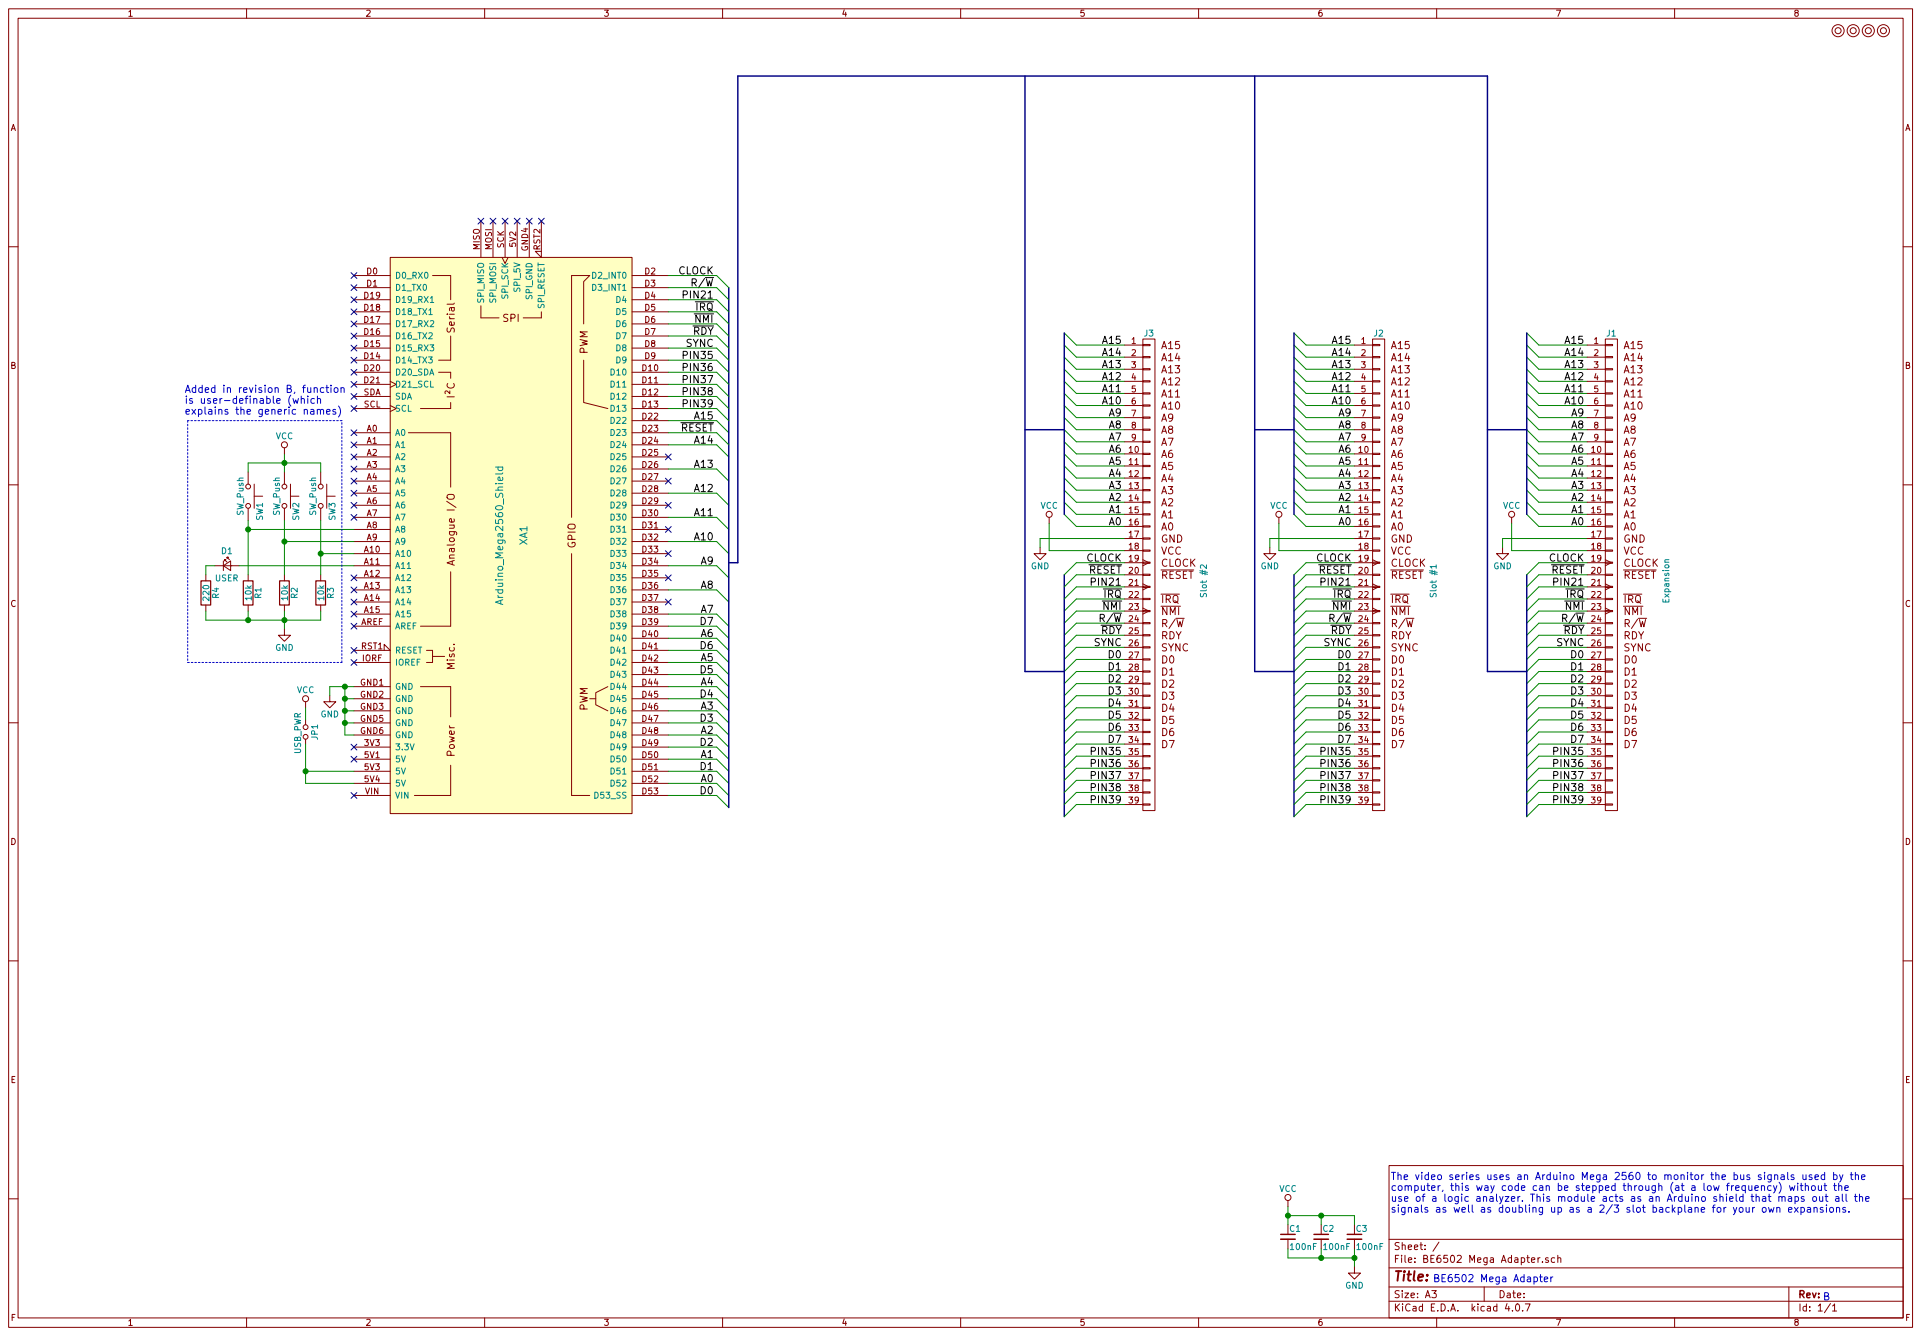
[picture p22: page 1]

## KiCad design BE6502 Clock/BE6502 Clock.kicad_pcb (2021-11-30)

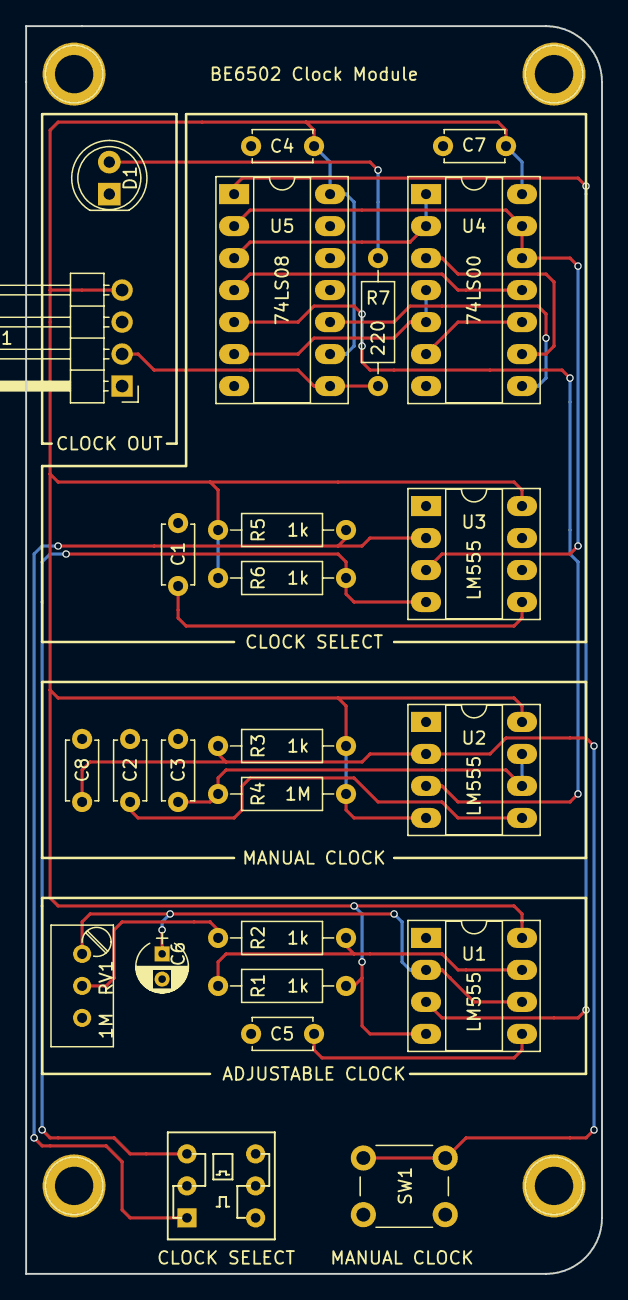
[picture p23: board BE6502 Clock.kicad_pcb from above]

Board: 2 copper layers, 45.7 x 99.1 mm, 29 parts (0 on the bottom side), 23 nets.

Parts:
C1, C2, C5: 10nF; C_Disc_D4.7mm_W2.5mm_P5.00mm
C3, C4, C7, C8: 100nF; C_Disc_D4.7mm_W2.5mm_P5.00mm
C6: 1uF; CP_Radial_D4.0mm_P2.00mm
D1: BLUE; LED_D5.0mm
J1: CLOCK_SEL; Pin_Header_Angled_1x04_Pitch2.54mm
M1, M2, M3, M4: Mounting; 1pin
R1, R2, R3, R5, R6: 1k; R_Axial_DIN0207_L6.3mm_D2.5mm_P10.16mm_Horizontal
R4: 1M; R_Axial_DIN0207_L6.3mm_D2.5mm_P10.16mm_Horizontal
R7: 220; R_Axial_DIN0207_L6.3mm_D2.5mm_P10.16mm_Horizontal
RV1: 1M; Potentiometer_Trimmer_Bourns_3296W
SW1: MANUAL; SW_PUSH_6mm
SW2: CLK_SEL; dpdt_switch
U1, U2, U3: LM555; DIP-8_W7.62mm_Socket_LongPads
U4: 74LS00; DIP-14_W7.62mm_Socket_LongPads
U5: 74LS08; DIP-14_W7.62mm_Socket_LongPads

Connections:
CLOCK_OUT: J1.2, R7.2, U5.8
GND: C1.2, C2.2, C3.2, C4.2, C5.2, C6.2, C7.2, C8.2, D1.1, J1.1, SW1.1, SW2.2, U1.1, U2.1, U3.1, U3.6, U4.7, U5.7, U5.12, U5.13
unnamed: C1.1, U3.5
unnamed: C2.1, U2.5
unnamed: C3.1, R4.2, U2.6, U2.7
unnamed: C5.1, U1.5
unnamed: C6.1, RV1.1, U1.2, U1.6
unnamed: C8.1, R3.2, SW1.2, U2.2
unnamed: D1.2, R7.1
unnamed: R1.2, R2.1, U1.7
unnamed: R2.2, RV1.2
unnamed: R5.2, SW2.1, U3.2
unnamed: R6.2, SW2.3, U3.4
unnamed: U1.3, U5.1
unnamed: U2.3, U5.5
unnamed: U3.3, U4.12, U4.13, U5.2
unnamed: U4.1, U4.2, U5.3
unnamed: U4.3, U4.9
unnamed: U4.4, U4.5, U5.6
unnamed: U4.8, U5.10
unnamed: U4.6, U4.10
unnamed: U4.11, U5.4
VCC: C4.1, C7.1, J1.4, R1.1, R3.1, R4.1, R5.1, R6.1, U1.4, U1.8, U2.4, U2.8, U3.8, U4.14, U5.9, U5.14

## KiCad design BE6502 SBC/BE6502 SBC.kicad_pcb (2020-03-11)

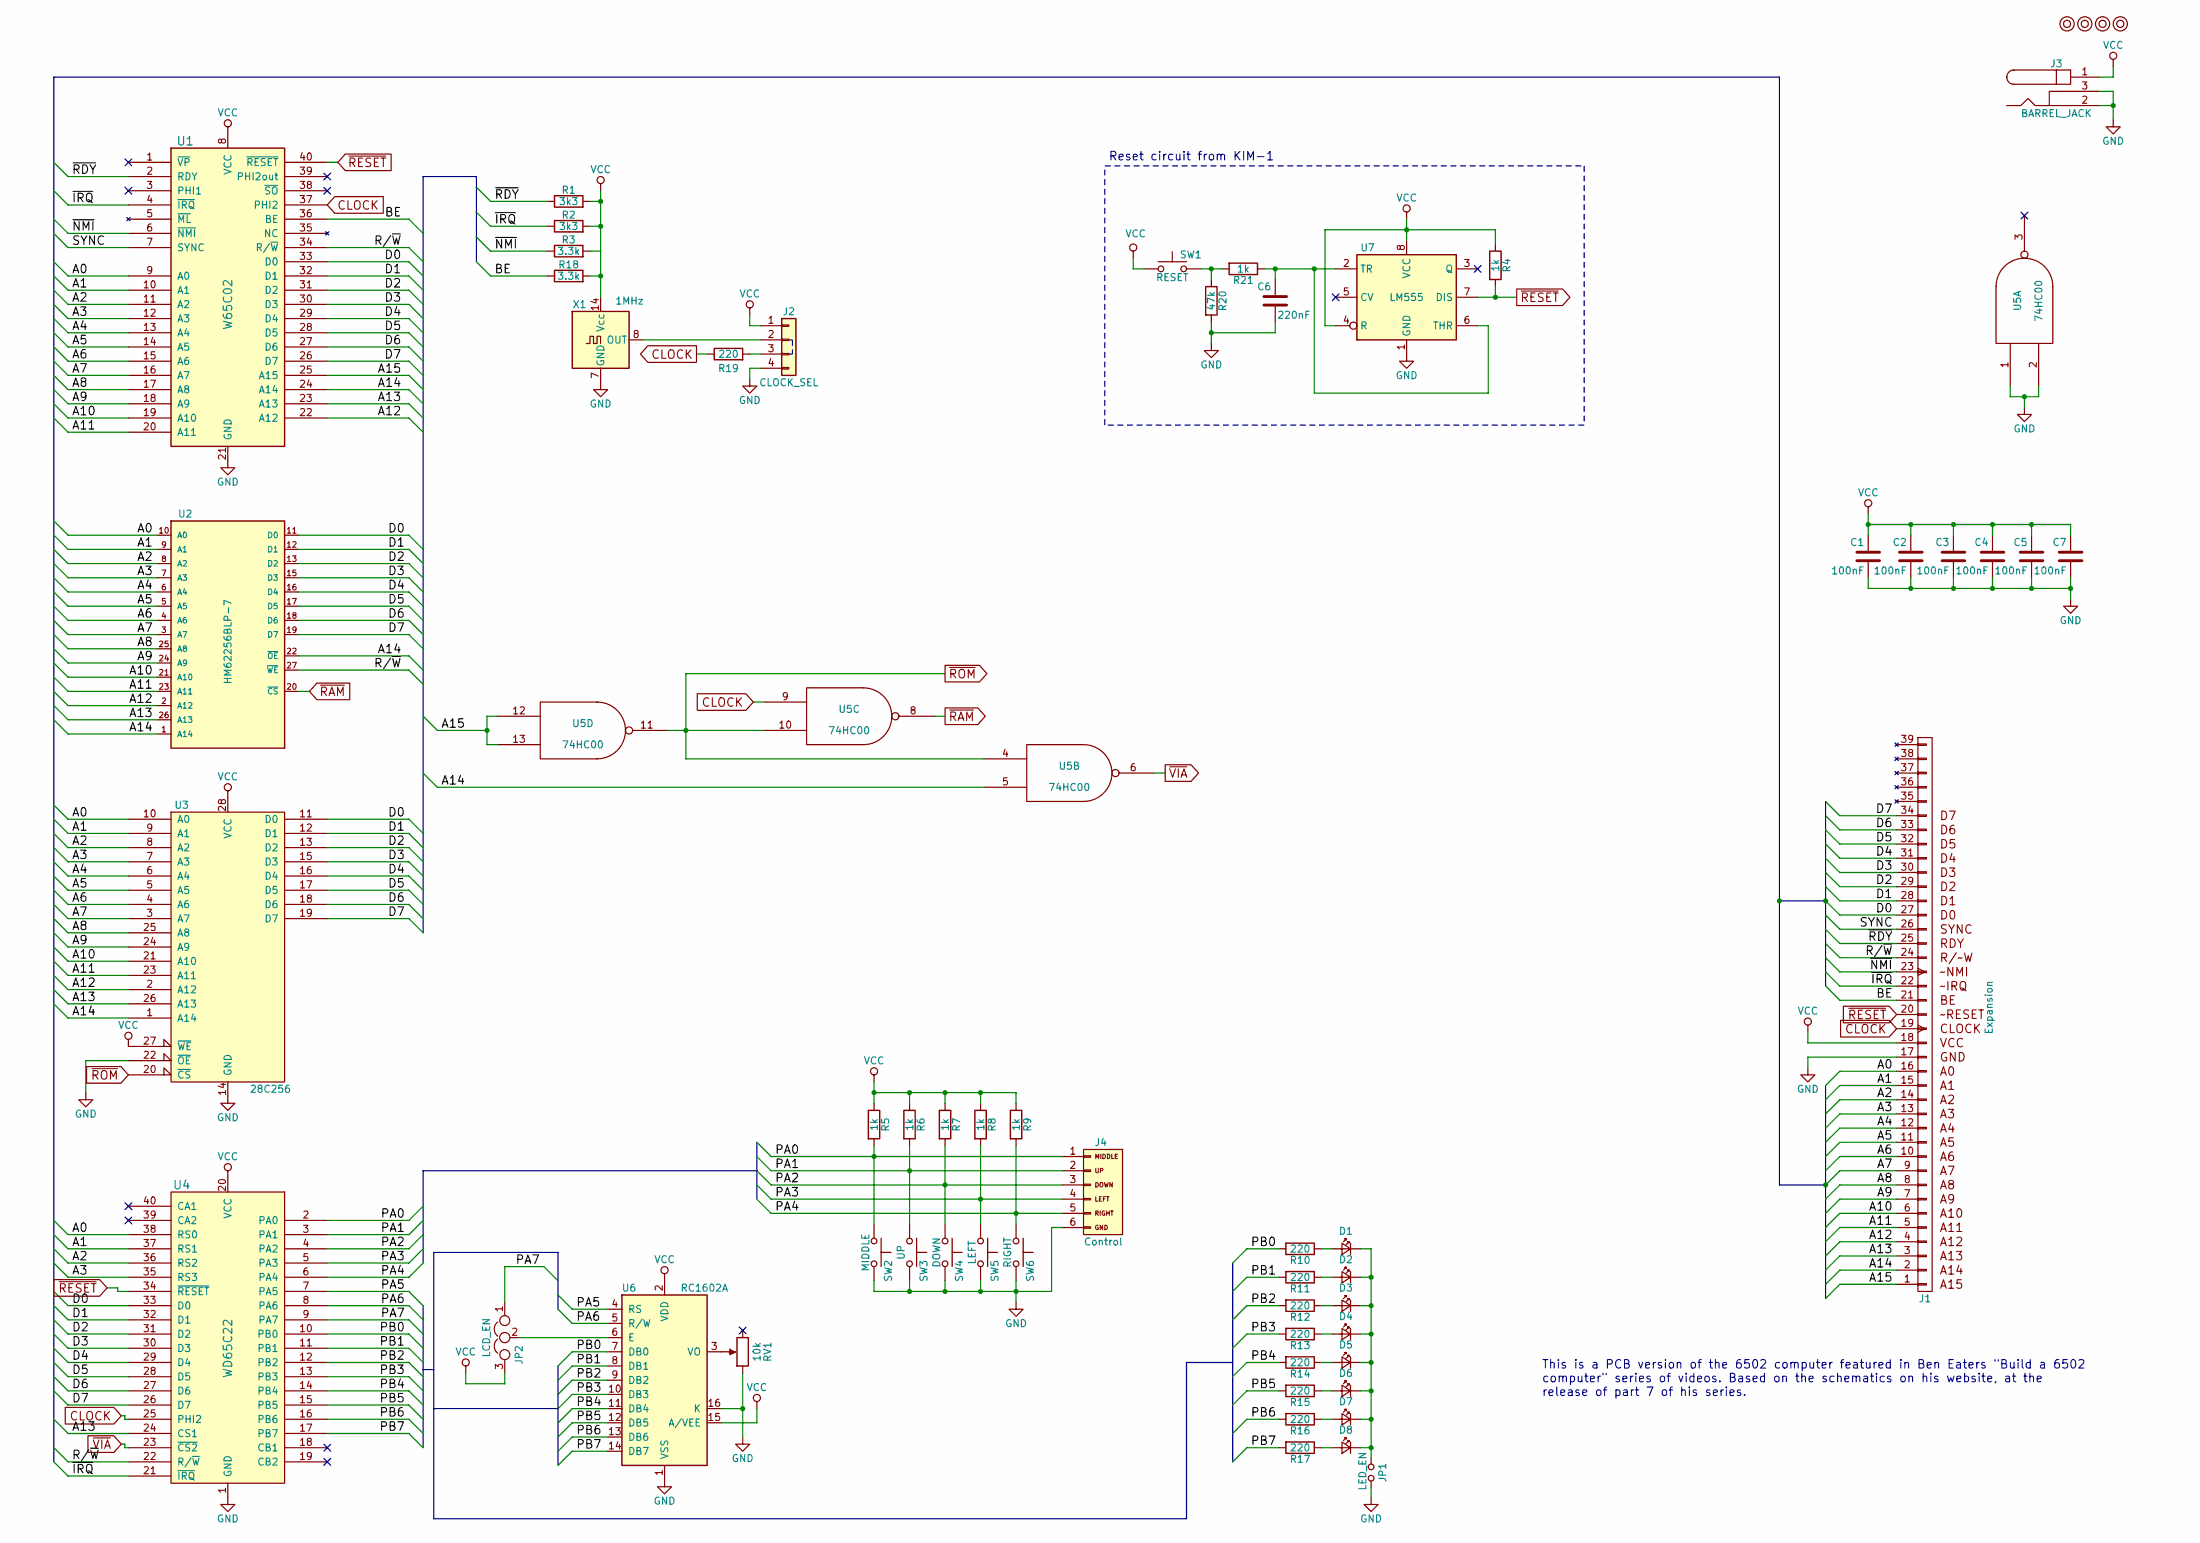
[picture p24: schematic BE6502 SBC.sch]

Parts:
C1, C2, C3, C4, C5, C7: 100nF; C_Disc_D4.7mm_W2.5mm_P5.00mm
C6: 220nF; C_Disc_D4.7mm_W2.5mm_P5.00mm
D1, D2, D3, D4, D5, D6, D7, D8: LED; LED_D5.0mm
J1: Expansion; Pin_Header_Angled_1x39_Pitch2.54mm
J2: CLOCK_SEL; Pin_Header_Angled_1x04_Pitch2.54mm
J3: BARREL_JACK
J4: Control; Pin_Header_Angled_1x06_Pitch2.54mm
JP1: LED_EN; Pin_Header_Straight_1x02_Pitch2.54mm
JP2: LCD_EN; Pin_Header_Straight_1x03_Pitch2.54mm
M1, M2, M3, M4: Mounting; 1pin
R1, R2: 3k3; R_Axial_DIN0207_L6.3mm_D2.5mm_P10.16mm_Horizontal
R3, R18: 3.3k; R_Axial_DIN0207_L6.3mm_D2.5mm_P10.16mm_Horizontal
R4, R5, R6, R7, R8, R9, R21: 1k; R_Axial_DIN0207_L6.3mm_D2.5mm_P10.16mm_Horizontal
R10, R11, R12, R13, R14, R15, R16, R17, R19: 220; R_Axial_DIN0207_L6.3mm_D2.5mm_P10.16mm_Horizontal
R20: 47k; R_Axial_DIN0207_L6.3mm_D2.5mm_P10.16mm_Horizontal
RV1: 10k; Potentiometer_Trimmer_Bourns_3296W
SW1: RESET; SW_PUSH_6mm
SW2: MIDDLE; SW_PUSH_6mm
SW3: UP; SW_PUSH_6mm
SW4: DOWN; SW_PUSH_6mm
SW5: LEFT; SW_PUSH_6mm
SW6: RIGHT; SW_PUSH_6mm
U1: W65C02; DIP-40_W15.24mm_Socket_LongPads
U2: HM62256BLP-7; DIP-28_W15.24mm_Socket_LongPads
U3: 28C256; DIP-28_W15.24mm_Socket_LongPads
U4: WD65C22; DIP-40_W15.24mm_Socket_LongPads
U5: 74HC00; DIP-14_W7.62mm_Socket_LongPads
U6: RC1602A; WC1602A
U7: LM555; DIP-8_W7.62mm_Socket_LongPads
X1: 1MHz; Oscillator_DIP-14

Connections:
/A0: J1.16 (A0), U1.9 (A0), U2.10 (A0), U3.10 (A0), U4.38 (RS0)
/A1: J1.15 (A1), U1.10 (A1), U2.9 (A1), U3.9 (A1), U4.37 (RS1)
/A2: J1.14 (A2), U1.11 (A2), U2.8 (A2), U3.8 (A2), U4.36 (RS2)
/A3: J1.13 (A3), U1.12 (A3), U2.7 (A3), U3.7 (A3), U4.35 (RS3)
/A4: J1.12 (A4), U1.13 (A4), U2.6 (A4), U3.6 (A4)
/A5: J1.11 (A5), U1.14 (A5), U2.5 (A5), U3.5 (A5)
/A6: J1.10 (A6), U1.15 (A6), U2.4 (A6), U3.4 (A6)
/A7: J1.9 (A7), U1.16 (A7), U2.3 (A7), U3.3 (A7)
/A8: J1.8 (A8), U1.17 (A8), U2.25 (A8), U3.25 (A8)
/A9: J1.7 (A9), U1.18 (A9), U2.24 (A9), U3.24 (A9)
/A10: J1.6 (A10), U1.19 (A10), U2.21 (A10), U3.21 (A10)
/A11: J1.5 (A11), U1.20 (A11), U2.23 (A11), U3.23 (A11)
/A12: J1.4 (A12), U1.22 (A12), U2.2 (A12), U3.2 (A12)
/A13: J1.3 (A13), U1.23 (A13), U2.26 (A13), U3.26 (A13), U4.24 (CS1)
/A14: J1.2 (A14), U1.24 (A14), U2.1 (A14), U2.22 (~OE), U3.1 (A14), U5.5
/A15: J1.1 (A15), U1.25 (A15), U5.12, U5.13
/BE: J1.21 (BE), R18.1, U1.36 (BE)
/D0: J1.27 (D0), U1.33 (D0), U2.11 (D0), U3.11 (D0), U4.33 (D0)
/D1: J1.28 (D1), U1.32 (D1), U2.12 (D1), U3.12 (D1), U4.32 (D1)
/D2: J1.29 (D2), U1.31 (D2), U2.13 (D2), U3.13 (D2), U4.31 (D2)
/D3: J1.30 (D3), U1.30 (D3), U2.15 (D3), U3.15 (D3), U4.30 (D3)
/D4: J1.31 (D4), U1.29 (D4), U2.16 (D4), U3.16 (D4), U4.29 (D4)
/D5: J1.32 (D5), U1.28 (D5), U2.17 (D5), U3.17 (D5), U4.28 (D5)
/D6: J1.33 (D6), U1.27 (D6), U2.18 (D6), U3.18 (D6), U4.27 (D6)
/D7: J1.34 (D7), U1.26 (D7), U2.19 (D7), U3.19 (D7), U4.26 (D7)
/PA0: J4.1 (MIDDLE), R5.2, SW2.1, U4.2 (PA0)
/PA1: J4.2 (UP), R6.2, SW3.1, U4.3 (PA1)
/PA2: J4.3 (DOWN), R7.2, SW4.1, U4.4 (PA2)
/PA3: J4.4 (LEFT), R8.2, SW5.1, U4.5 (PA3)
/PA4: J4.5 (RIGHT), R9.2, SW6.1, U4.6 (PA4)
/PA5: U4.7 (PA5), U6.4 (RS)
/PA6: U4.8 (PA6), U6.5 (R/W)
/PA7: JP2.1, U4.9 (PA7)
/PB0: R10.2, U4.10 (PB0), U6.7 (DB0)
/PB1: R11.2, U4.11 (PB1), U6.8 (DB1)
/PB2: R12.2, U4.12 (PB2), U6.9 (DB2)
/PB3: R13.2, U4.13 (PB3), U6.10 (DB3)
/PB4: R14.2, U4.14 (PB4), U6.11 (DB4)
/PB5: R15.2, U4.15 (PB5), U6.12 (DB5)
/PB6: R16.2, U4.16 (PB6), U6.13 (DB6)
/PB7: R17.2, U4.17 (PB7), U6.14 (DB7)
/R/~W: J1.24 (RW), U1.34 (R/~W), U2.27 (~WE), U4.22 (R/~W)
/SYNC: J1.26 (SYNC), U1.7 (SYNC)
/~IRQ: J1.22 (IRQ), R2.1, U1.4 (~IRQ), U4.21 (~IRQ)
/~NMI: J1.23 (PHI1), R3.1, U1.6 (~NMI)
/~RDY: J1.25 (READY), R1.1, U1.2 (RDY)
CLOCK: J1.19 (PHI2), R19.1, U1.37 (PHI2), U4.25 (PHI2), U5.9
GND: C1.2, C2.2, C3.2, C4.2, C5.2, C6.2, C7.2, J1.17, J2.4, J3.2, J3.3, J4.6 (GND), JP1.1, R20.2, RV1.1, SW2.2, SW3.2, SW4.2, SW5.2, SW6.2, U1.21 (GND), U2.14 (GND), U3.14 (GND), U3.22 (~OE), U4.1 (GND), U5.1, U5.2, U5.7 (GND), U6.1 (VSS), U6.16 (K), U7.1 (GND), X1.7 (GND)
unnamed: C6.1, R21.1, U7.2 (TR), U7.6 (THR)
unnamed: D1.1 (K), D2.1 (K), D3.1 (K), D4.1 (K), D5.1 (K), D6.1 (K), D7.1 (K), D8.1 (K), JP1.2
unnamed: D1.2 (A), R10.1
unnamed: D2.2 (A), R11.1
unnamed: D3.2 (A), R12.1
unnamed: D4.2 (A), R13.1
unnamed: D5.2 (A), R14.1
unnamed: D6.2 (A), R15.1
unnamed: D7.2 (A), R16.1
unnamed: D8.2 (A), R17.1
unnamed: J2.2, X1.8 (OUT)
unnamed: J2.3, R19.2
unnamed: JP2.2, U6.6 (E)
unnamed: R20.1, R21.2, SW1.2
unnamed: RV1.2, U6.3 (VO)
VCC: C1.1, C2.1, C3.1, C4.1, C5.1, C7.1, J1.18, J2.1, J3.1, JP2.3, R1.2, R2.2, R3.2, R4.1, R5.1, R6.1, R7.1, R8.1, R9.1, R18.2, SW1.1, U1.8 (VCC), U2.28 (VCC), U3.27 (~WE), U3.28 (VCC), U4.20 (VCC), U5.14 (VCC), U6.2 (VDD), U6.15 (A/VEE), U7.4 (R), U7.8 (VCC), X1.14 (Vcc)
~RAM: U2.20 (~CS), U5.8
~RESET: J1.20 (RESET), R4.2, U1.40 (~RESET), U4.34 (~RESET), U7.7 (DIS)
~ROM: U3.20 (~CS), U5.4, U5.10, U5.11
~VIA: U4.23 (~CS2), U5.6

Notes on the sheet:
This is a PCB version of the 6502 computer featured in Ben Eaters "Build a 6502 computer" series of videos. Based on the schematics on his website, at the release of part 7 of his series.
Reset circuit from KIM-1

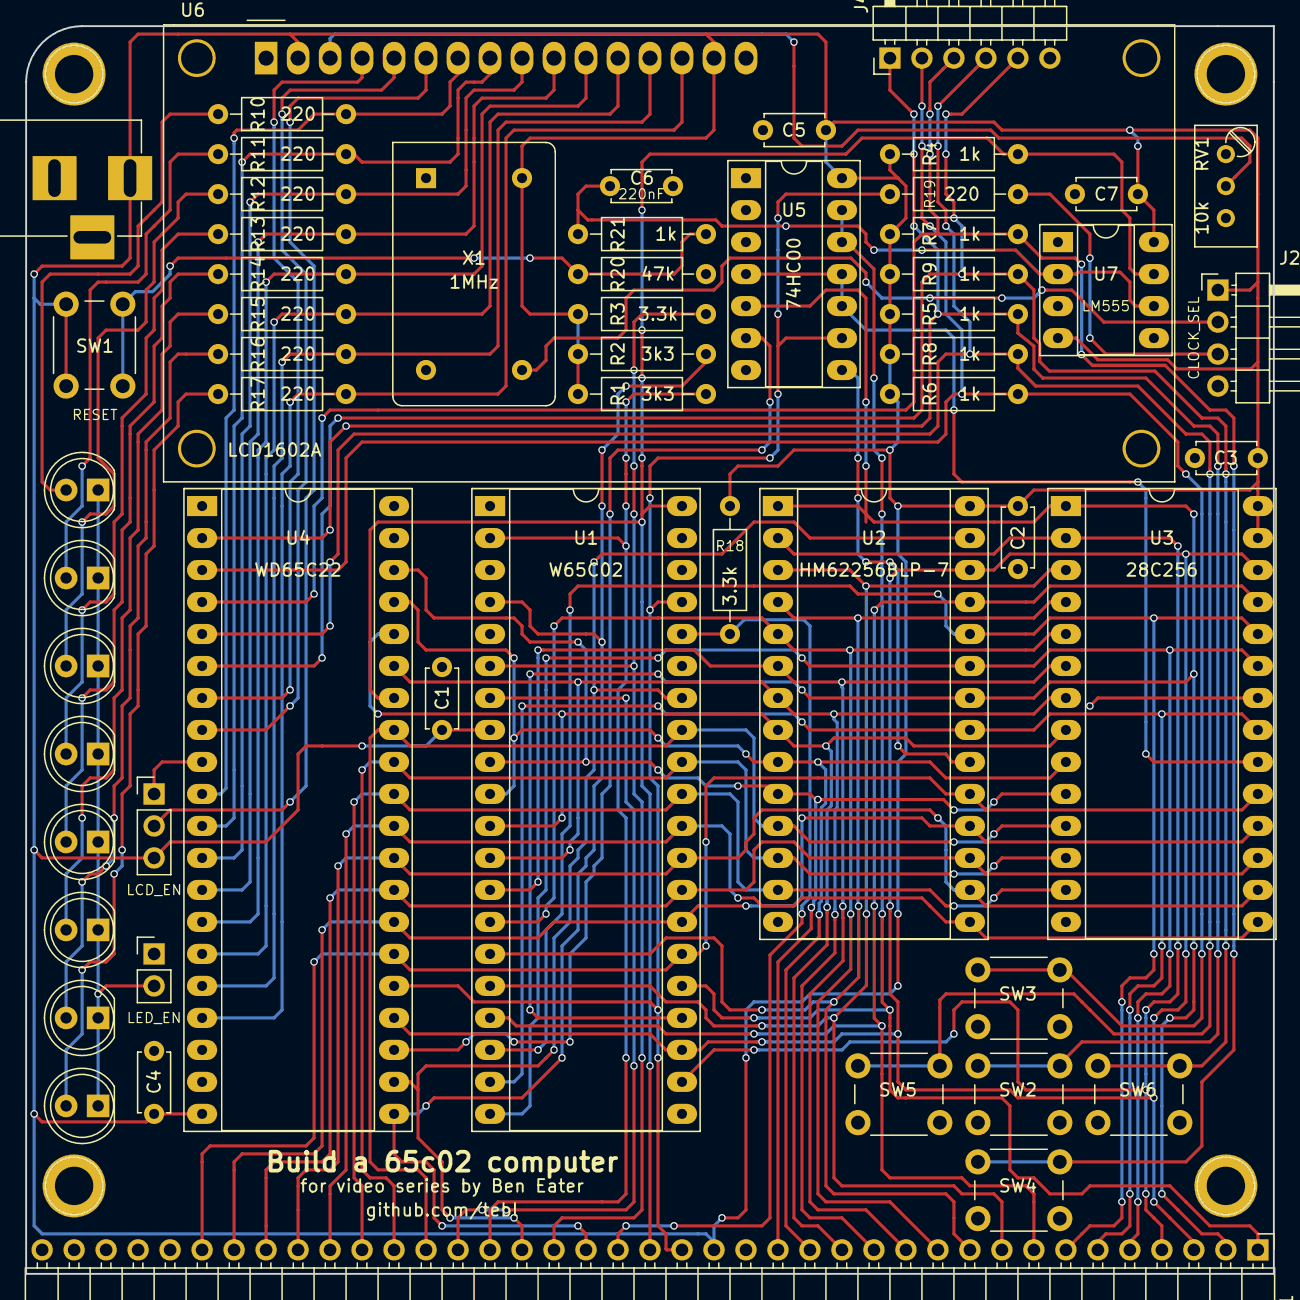
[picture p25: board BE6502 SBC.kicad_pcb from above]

Board: 2 copper layers, 99.1 x 99.1 mm, 61 parts (0 on the bottom side), 68 nets.

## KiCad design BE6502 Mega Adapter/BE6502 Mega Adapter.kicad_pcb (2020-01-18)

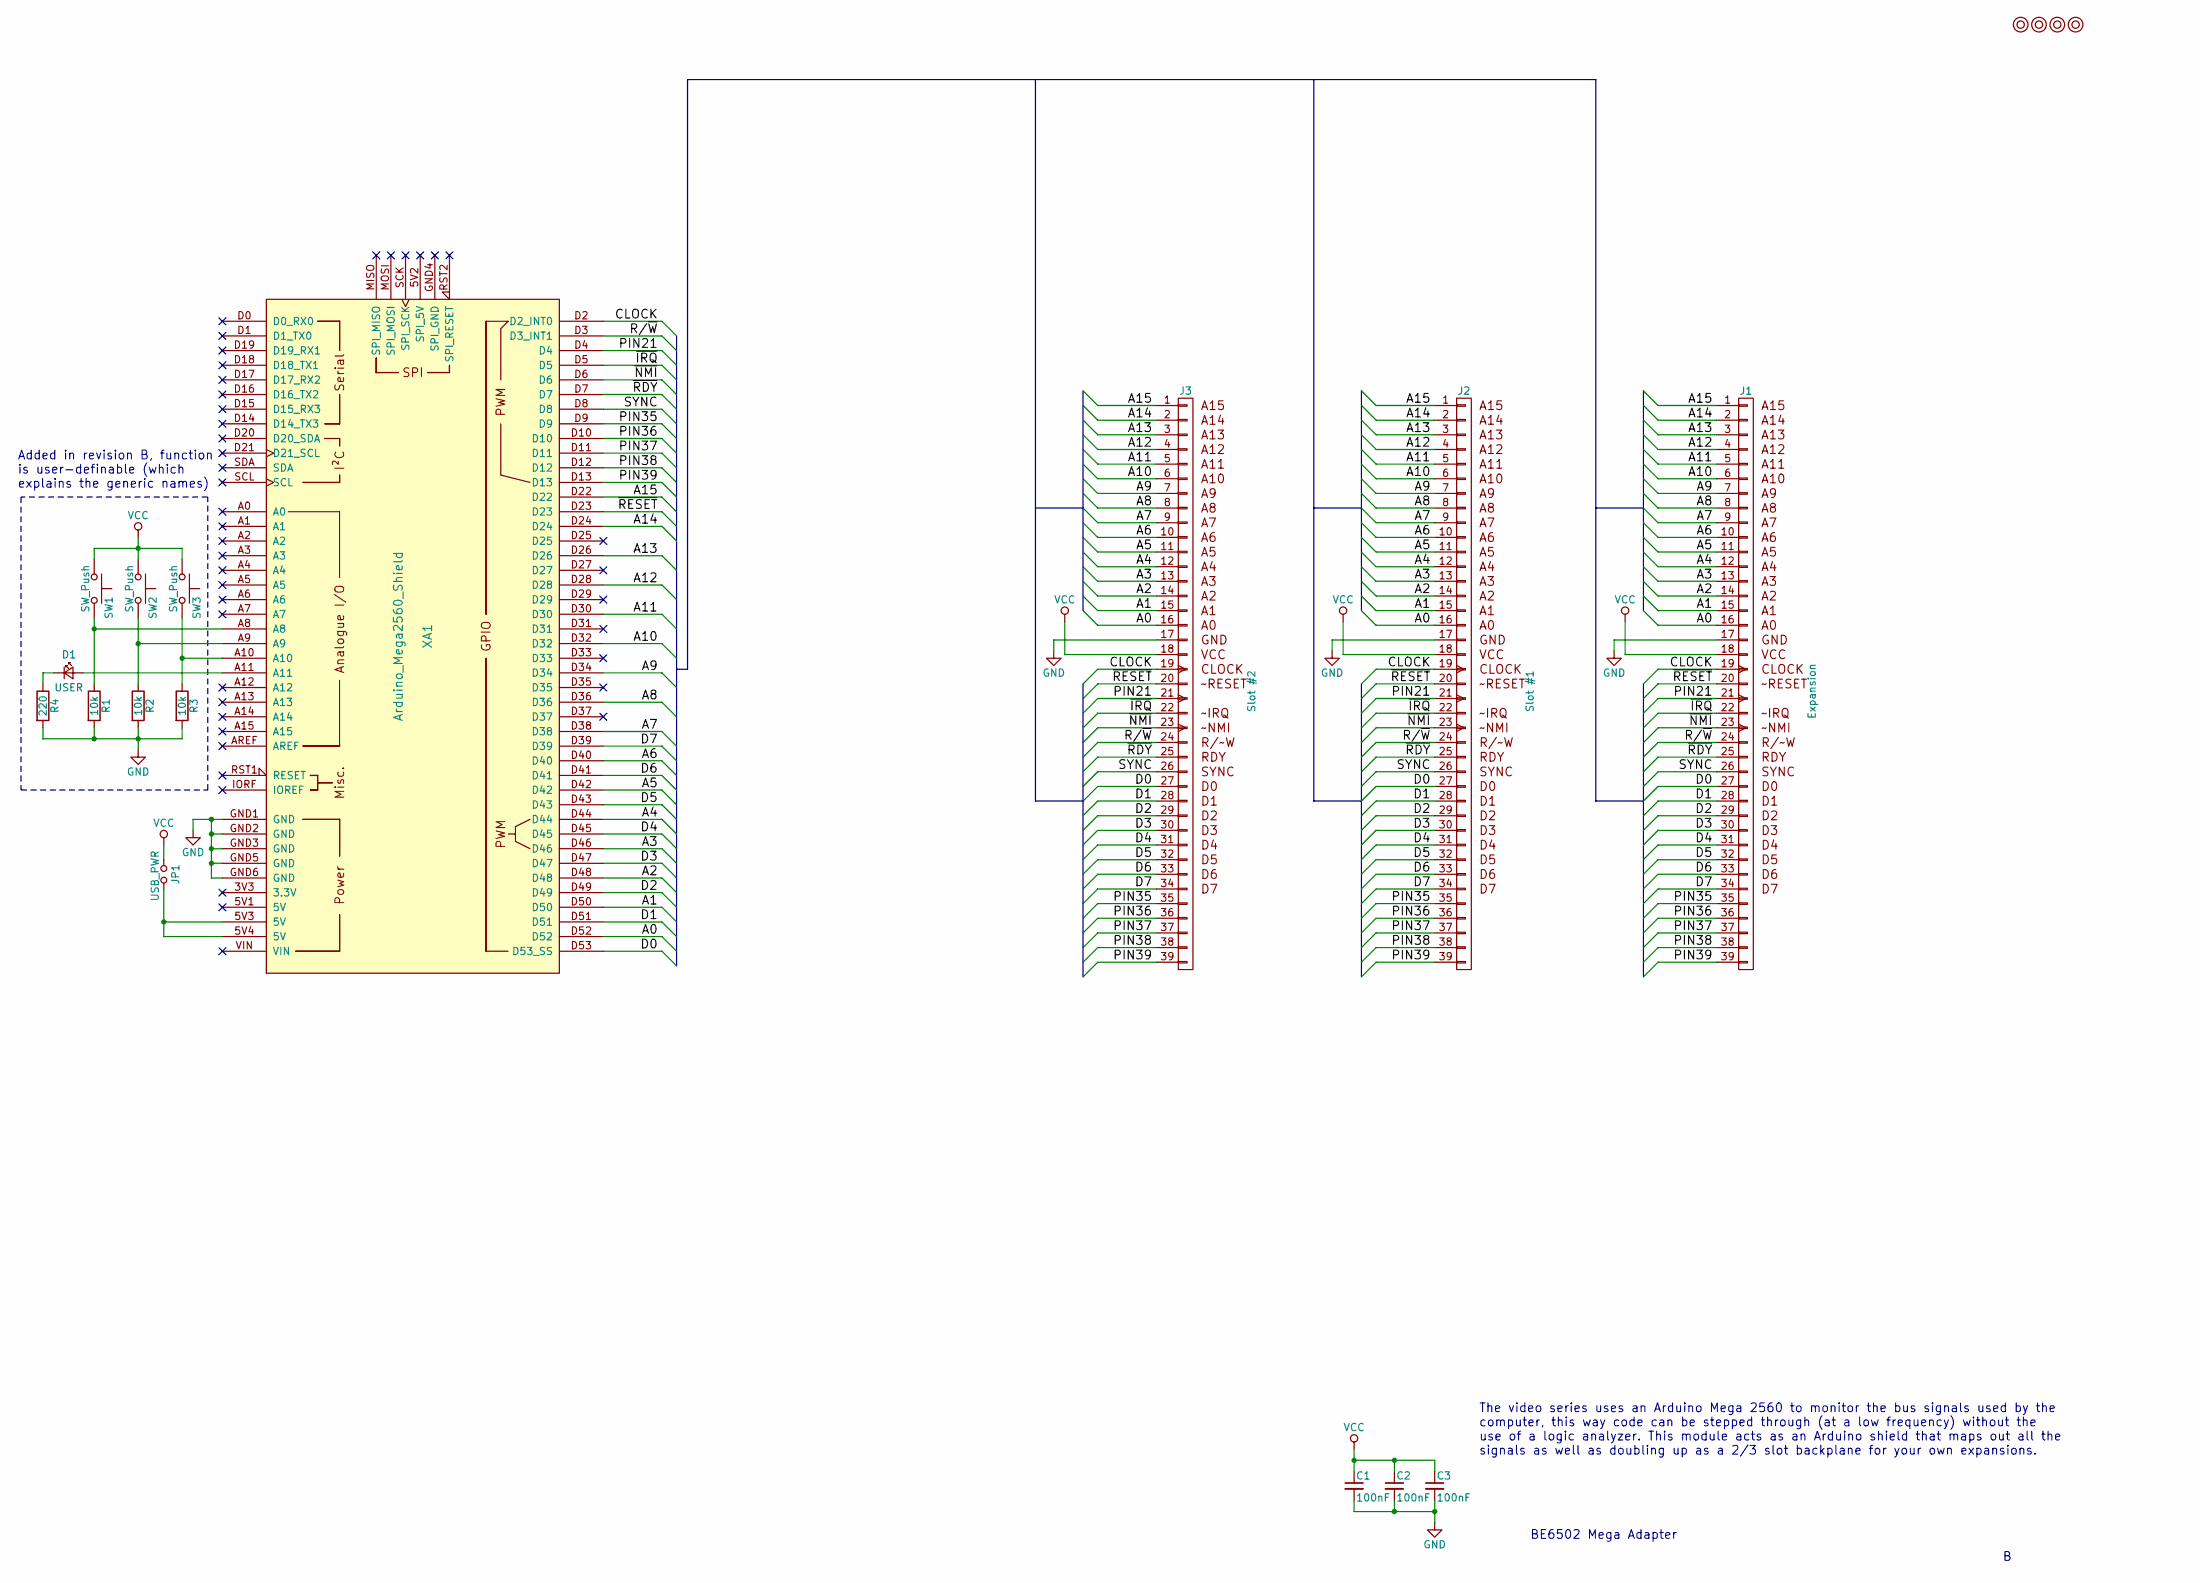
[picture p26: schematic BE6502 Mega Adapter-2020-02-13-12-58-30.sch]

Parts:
C1, C2, C3: 100nF; C_Disc_D4.7mm_W2.5mm_P5.00mm
D1: USER; LED_D5.0mm
J1: Expansion; Pin_Header_Angled_1x39_Pitch2.54mm
J2: Slot #1; Pin_Header_Straight_1x39_Pitch2.54mm
J3: Slot #2; Pin_Header_Straight_1x39_Pitch2.54mm
JP1: USB_PWR; Pin_Header_Straight_1x02_Pitch2.54mm
M1, M2, M3, M4: Mounting; 1pin
R1, R2, R3: 10k; R_Axial_DIN0207_L6.3mm_D2.5mm_P10.16mm_Horizontal
R4: 220; R_Axial_DIN0207_L6.3mm_D2.5mm_P10.16mm_Horizontal
SW1, SW2, SW3: SW_Push; SW_PUSH_6mm
XA1: Arduino_Mega2560_Shield

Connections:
/A0: J1.16 (A0), J2.16 (A0), J3.16 (A0), XA1.D52
/A1: J1.15 (A1), J2.15 (A1), J3.15 (A1), XA1.D50
/A2: J1.14 (A2), J2.14 (A2), J3.14 (A2), XA1.D48
/A3: J1.13 (A3), J2.13 (A3), J3.13 (A3), XA1.D46
/A4: J1.12 (A4), J2.12 (A4), J3.12 (A4), XA1.D44
/A5: J1.11 (A5), J2.11 (A5), J3.11 (A5), XA1.D42
/A6: J1.10 (A6), J2.10 (A6), J3.10 (A6), XA1.D40
/A7: J1.9 (A7), J2.9 (A7), J3.9 (A7), XA1.D38
/A8: J1.8 (A8), J2.8 (A8), J3.8 (A8), XA1.D36
/A9: J1.7 (A9), J2.7 (A9), J3.7 (A9), XA1.D34
/A10: J1.6 (A10), J2.6 (A10), J3.6 (A10), XA1.D32
/A11: J1.5 (A11), J2.5 (A11), J3.5 (A11), XA1.D30
/A12: J1.4 (A12), J2.4 (A12), J3.4 (A12), XA1.D28
/A13: J1.3 (A13), J2.3 (A13), J3.3 (A13), XA1.D26
/A14: J1.2 (A14), J2.2 (A14), J3.2 (A14), XA1.D24
/A15: J1.1 (A15), J2.1 (A15), J3.1 (A15), XA1.D22
/CLOCK: J1.19 (PHI2), J2.19 (PHI2), J3.19 (PHI2), XA1.D2 (D2_INT0)
/D0: J1.27 (D0), J2.27 (D0), J3.27 (D0), XA1.D53 (D53_SS)
/D1: J1.28 (D1), J2.28 (D1), J3.28 (D1), XA1.D51
/D2: J1.29 (D2), J2.29 (D2), J3.29 (D2), XA1.D49
/D3: J1.30 (D3), J2.30 (D3), J3.30 (D3), XA1.D47
/D4: J1.31 (D4), J2.31 (D4), J3.31 (D4), XA1.D45
/D5: J1.32 (D5), J2.32 (D5), J3.32 (D5), XA1.D43
/D6: J1.33 (D6), J2.33 (D6), J3.33 (D6), XA1.D41
/D7: J1.34 (D7), J2.34 (D7), J3.34 (D7), XA1.D39
/PIN21: J1.21 (PHI0), J2.21 (PHI0), J3.21 (PHI0), XA1.D4
/PIN35: J1.35 (TX), J2.35 (TX), J3.35 (TX), XA1.D9
/PIN36: J1.36 (RX), J2.36 (RX), J3.36 (RX), XA1.D10
/PIN37: J1.37 (NMI), J2.37 (NMI), J3.37 (NMI), XA1.D11
/PIN38: J1.38, J2.38, J3.38, XA1.D12
/PIN39: J1.39, J2.39, J3.39, XA1.D13
/R/~W: J1.24 (RW), J2.24 (RW), J3.24 (RW), XA1.D3 (D3_INT1)
/SYNC: J1.26 (SYNC), J2.26 (SYNC), J3.26 (SYNC), XA1.D8
/~IRQ: J1.22 (IRQ), J2.22 (IRQ), J3.22 (IRQ), XA1.D5
/~NMI: J1.23 (PHI1), J2.23 (PHI1), J3.23 (PHI1), XA1.D6
/~RDY: J1.25 (READY), J2.25 (READY), J3.25 (READY), XA1.D7
/~RESET: J1.20 (RESET), J2.20 (RESET), J3.20 (RESET), XA1.D23
GND: C1.2, C2.2, C3.2, J1.17, J2.17, J3.17, R1.2, R2.2, R3.2, R4.2, XA1.GND1 (GND), XA1.GND2 (GND), XA1.GND3 (GND), XA1.GND5 (GND), XA1.GND6 (GND)
unnamed: D1.1 (K), R4.1
unnamed: D1.2 (A), XA1.A11
unnamed: JP1.2, XA1.5V3 (5V), XA1.5V4 (5V)
unnamed: R1.1, SW1.2, XA1.A8
unnamed: R2.1, SW2.2, XA1.A9
unnamed: R3.1, SW3.2, XA1.A10
VCC: C1.1, C2.1, C3.1, J1.18, J2.18, J3.18, JP1.1, SW1.1, SW2.1, SW3.1

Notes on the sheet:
BE6502 Mega Adapter
The video series uses an Arduino Mega 2560 to monitor the bus signals used by the computer, this way code can be stepped through (at a low frequency) without the use of a logic analyzer. This module acts as an Arduino shield that maps out all the signals as well as doubling up as a 2/3 slot backpla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
Added in revision B, function is user-definable (which explains the generic names)

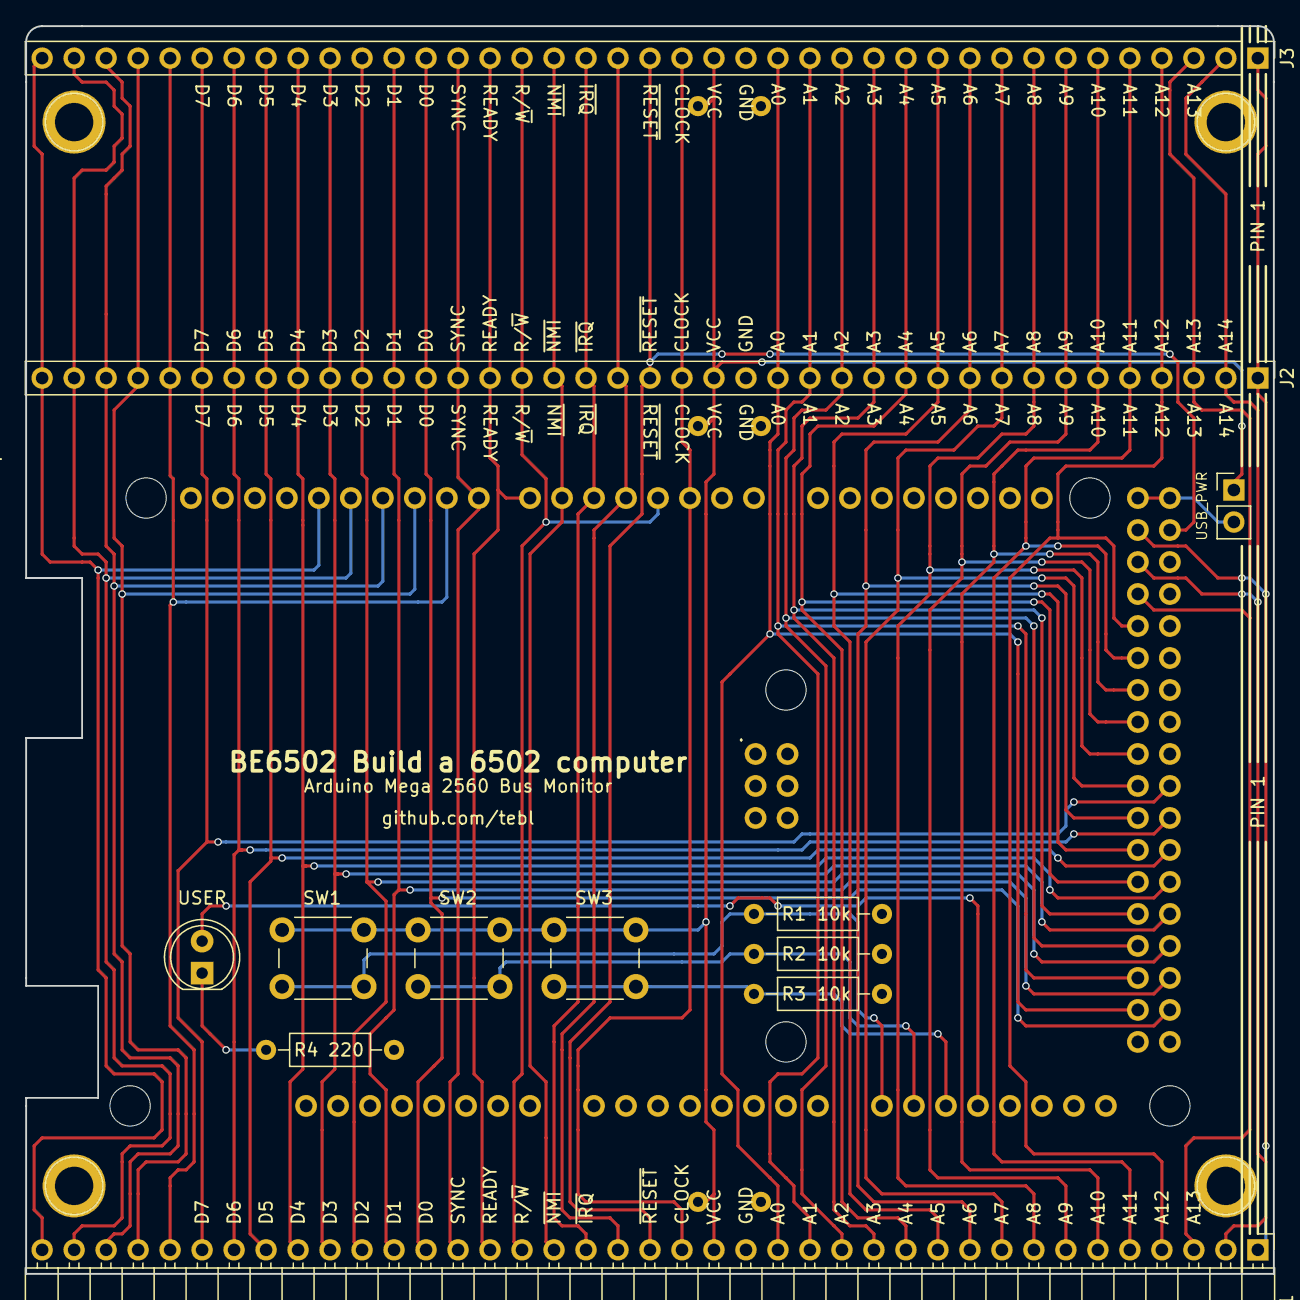
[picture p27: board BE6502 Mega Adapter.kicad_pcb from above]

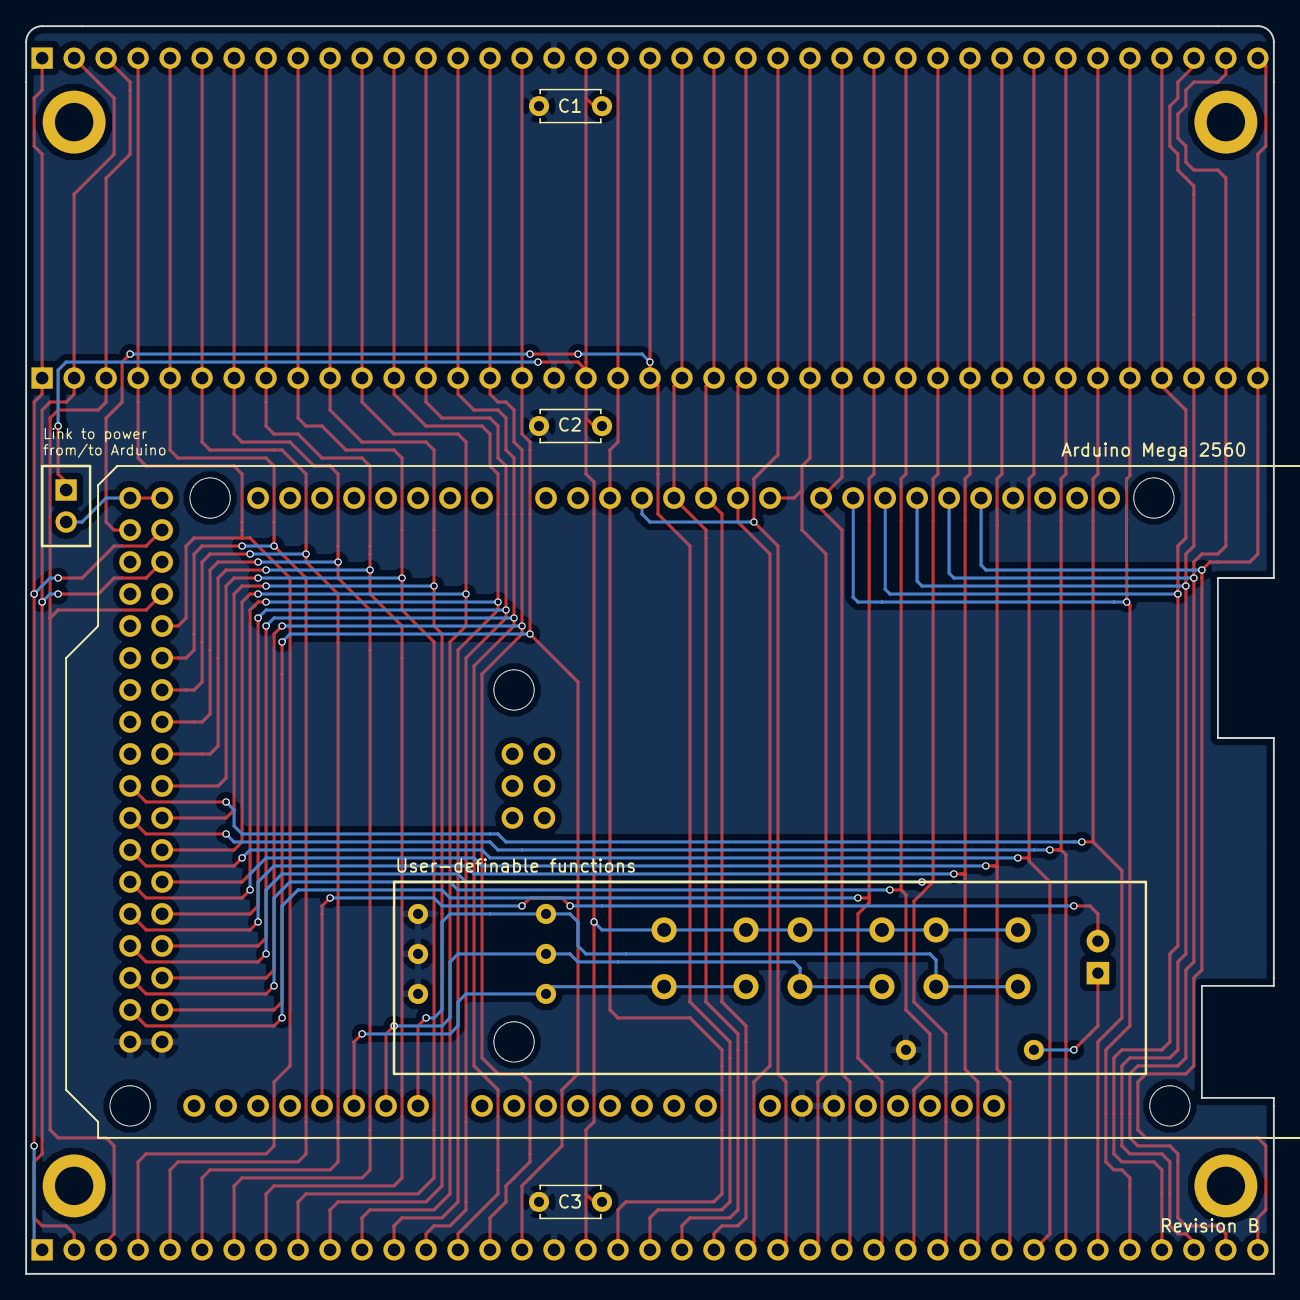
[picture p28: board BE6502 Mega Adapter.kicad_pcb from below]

Board: 2 copper layers, 99.1 x 99.1 mm, 20 parts (3 on the bottom side), 45 nets.

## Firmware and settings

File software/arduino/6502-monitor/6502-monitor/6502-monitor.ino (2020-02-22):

#include <Arduino.h>
#include <TimerThree.h>
#include "constants.h"
#include "commands.h"
#include "process_serial.h"
#include "process_switches.h"
#include "bus_control.h"

/* Able to use VT100 commands on serial, disable if you get wierd characters
 * in serial output - or switch to a serial terminal that supports them.
 */
bool ansi_enabled = true;     

/* Enable bus monitor output */
volatile bool suppress_monitor = false;
bool int_enabled = false;

/* Controls the ability of the Arduino Mega 2560 to generate the system clock,
 * but since we don't want two clocks fighting eachother this is normally
 * disabled until explicitly enabled.
 */
int clock_mode = CLK_MODE_NONE;
int clock_setting = 0;

void setup() {
  Serial.begin(115200);
  for (int n = 0; n < 16; n += 1) {
    pinMode(SBC_ADDR[n], INPUT);
  }
  for (int n = 0; n < 8; n += 1) {
    pinMode(SBC_DATA[n], INPUT);
  }

  pinMode(USER_LED, OUTPUT);
  pinMode(USER_SW1, INPUT);
  pinMode(USER_SW2, INPUT);
  pinMode(USER_SW3, INPUT);

  pinMode(SBC_CLOCK, INPUT);
  pinMode(SBC_RW, INPUT);
  pinMode(SBC_BE, INPUT);
  pinMode(SBC_READY, INPUT);
  
  commands_init();
  print_welcome();
}

void loop() {
    while(Serial.available() > 0) {
        process_serial(Serial.read());
    }
    process_switches();
}

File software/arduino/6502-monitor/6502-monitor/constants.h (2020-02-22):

#define VERSION "0.2"
#define BAUD_RATE 115200
#define MAX_INPUT_SIZE 100
#define TERMINAL_COLS 80
//#define DEBUG

/* Pin definitions */
#define SBC_CLOCK 2
#define SBC_RW 3
#define SBC_IRQ 5
#define SBC_NMI 6
#define SBC_BE 4
#define SBC_READY 7
#define SBC_SYNC 8
#define SBC_RESET 23

#define SBC_A15 22
#define SBC_A14 24
#define SBC_A13 26
#define SBC_A12 28
#define SBC_A11 30
#define SBC_A10 32
#define SBC_A9 34
#define SBC_A8 36
#define SBC_A7 38
#define SBC_A6 40
#define SBC_A5 42
#define SBC_A4 44
#define SBC_A3 46
#define SBC_A2 48
#define SBC_A1 50
#define SBC_A0 52
const char SBC_ADDR[] = {22, 24, 26, 28, 30, 32, 34, 36, 38, 40, 42, 44, 46, 48, 50, 52};

#define SBC_D7 39
#define SBC_D6 41
#define SBC_D5 43
#define SBC_D4 45
#define SBC_D3 47
#define SBC_D2 49
#define SBC_D1 51
#define SBC_D0 53
const char SBC_DATA[] = {39, 41, 43, 45, 47, 49, 51, 53};

#define SBC_PIN35 9
#define SBC_PIN36 10
#define SBC_PIN37 11
#define SBC_PIN38 12
#define SBC_PIN39 13

#define USER_LED 65
#define USER_SW1 62
#define USER_SW2 63
#define USER_SW3 64

/* Arduino clock modes */
#define CLK_MODE_NONE 0
#define CLK_MODE_MANUAL 1
#define CLK_MODE_AUTO 2
/*                            1Hz     2Hz     4Hz    16Hz   32Hz   128   256 */
const long CLK_PERIOD[] = {1000000, 500000, 250000, 62500, 31250, 7812, 3906};
#define CLK_SPEED_1 0
#define CLK_SPEED_2 1
#define CLK_SPEED_4 2
#define CLK_SPEED_16 3
#define CLK_SPEED_32 4
#define CLK_SPEED_128 5
#define CLK_SPEED_256 6
#define CLK_MAX_SETTING CLK_SPEED_256
#define CLK_MAX_MONITOR_SPEED CLK_SPEED_32

/* SBC Address Segments */
#define ADR_UNSPECIFIED 0
#define ADR_RAM 1
#define ADR_ZERO_PAGE 2
#define ADR_STACK 3
#define ADR_VIA 4
#define ADR_CUSTOM 5
#define ADR_ROM 6
#define ADR_VECTORS 7

#define COMMAND_SET_MAIN 0
#define COMMAND_SET_CONTROL 1

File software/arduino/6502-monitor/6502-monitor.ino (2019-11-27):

const char ADDR[] = {22, 24, 26, 28, 30, 32, 34, 36, 38, 40, 42, 44, 46, 48, 50, 52};
const char DATA[] = {39, 41, 43, 45, 47, 49, 51, 53};
#define CLOCK 2
#define READ_WRITE 3

void setup() {
  for (int n = 0; n < 16; n += 1) {
    pinMode(ADDR[n], INPUT);
  }
  for (int n = 0; n < 8; n += 1) {
    pinMode(DATA[n], INPUT);
  }
  pinMode(CLOCK, INPUT);
  pinMode(READ_WRITE, INPUT);

  attachInterrupt(digitalPinToInterrupt(CLOCK), onClock, RISING);
  
  Serial.begin(115200);
}

void onClock() {
  char output[15];

  unsigned int address = 0;
  for (int n = 0; n < 16; n += 1) {
    int bit = digitalRead(ADDR[n]) ? 1 : 0;
    Serial.print(bit);
    address = (address << 1) + bit;
  }
  
  Serial.print("   ");
  
  unsigned int data = 0;
  for (int n = 0; n < 8; n += 1) {
    int bit = digitalRead(DATA[n]) ? 1 : 0;
    Serial.print(bit);
    data = (data << 1) + bit;
  }

  sprintf(output, "   %04X  %c %02X", address, digitalRead(READ_WRITE) ? 'r' : 'W', data);
  Serial.println(output);  
}

void loop() {
}

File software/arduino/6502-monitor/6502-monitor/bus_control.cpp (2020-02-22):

#include <Arduino.h>
#include "constants.h"
#include "bus_control.h"
#include "debug.h"
#include "ansi.h"
#include "clock.h"
#include "commands.h"

extern int clock_mode;

extern int command_set;
bool bus_asserted = false;

/*
 * Set the direction of the pins currently facing the computers data bus, this
 * needs to be done so that it corresponds to whatever signalling we are
 * performing. Note that incorrect use will lead to a dead Arduino, SBC or
 * both!
 */
void set_data_direction(int direction) {
  digitalWrite(SBC_RW, HIGH);
  switch (direction) {
    case DATA_DIRECTION_READ:
      debug(F("Set data direction: READ"));
      for (int i = 0; i < 8; i++) {
        pinMode(SBC_DATA[i], INPUT);
      }
      break;

    case DATA_DIRECTION_WRITE:
      debug(F("Set data direction: WRITE"));
      for (int i = 0; i < 8; i++) {
        pinMode(SBC_DATA[i], OUTPUT);
      }
      break;
  }
}

/* 
 * Assert control of address and data bus to enable direct control of the
 * various associated peripherals. Note that this assumes that we are able
 * to control the clock.
 */
void bus_assert() {
  if (bus_asserted) return;
  bus_asserted = true;

  int_detach();

  debug(F("Assert READY"));
  digitalWrite(SBC_READY, LOW);
  pinMode(SBC_READY, OUTPUT);

  debug(F("Clock HIGH"));
  digitalWrite(SBC_CLOCK, HIGH);

  debug(F("Assert BE"));
  digitalWrite(SBC_BE, LOW);
  pinMode(SBC_BE, OUTPUT);

  debug(F("Control R/W"));  
  digitalWrite(SBC_RW, HIGH);
  pinMode(SBC_RW, OUTPUT);

  debug(F("Controlling A0-A15"));
  for (int n = 0; n < 16; n += 1) {
    pinMode(SBC_ADDR[n], OUTPUT);
    digitalWrite(SBC_ADDR[n], HIGH);
  }

  set_data_direction(DATA_DIRECTION_READ);
}

/*
 * Release the bus, allowing the w65c02 to resume whatever it was doing before
 * we forced it offline. More than likely we've done so at a time where it
 * wasn't completely recoverable so you should probably be prepared to reset
 * it anyway!
 */
void bus_release() {
  if (!bus_asserted) return;
  set_data_direction(DATA_DIRECTION_READ);

  debug(F("Release A0-A15"));
  for (int n = 0; n < 16; n += 1) {
    pinMode(SBC_ADDR[n], INPUT);
  }

  debug(F("Release R/W"));
  pinMode(SBC_RW, INPUT);

  debug(F("Deassert BE"));
  digitalWrite(SBC_BE, HIGH);
  pinMode(SBC_BE, OUTPUT);

  debug(F("Clock LOW"));
  digitalWrite(SBC_CLOCK, LOW);

  debug(F("Deassert READY"));
  digitalWrite(SBC_READY, HIGH);
  pinMode(SBC_READY, INPUT);

  int_attach();

  bus_asserted = false;
}

/*
 * Set address pins, unsigned to allow for the full 65K address space.
 */
void set_address(const unsigned long address) {
  unsigned long value = address;
  for (int i = 15; i >= 0; i--) {
    digitalWrite(SBC_ADDR[i], value & 1);
    value = value >> 1;
  }
}

/*
 * Read a byte from the data pins, use set_direction to perform sequential
 * reads without having to set up data direction every time (it's slow
 * enough as it is).
 */
byte read_byte(bool set_direction = true) {
  if (set_direction) set_data_direction(DATA_DIRECTION_READ);

  byte value = 0;
  for (int i = 0; i < 8; i++) {
    value = (value << 1) + digitalRead(SBC_DATA[i]);
  }
  return value;
}

/* 
 * Write a byte to the data pins, use set_direction to perform sequential
 * writes without having to set up data direction every time. Assumes that
 * the clock is already HI.
 */
void write_byte(byte value, bool set_direction = true) {
  if (set_direction) set_data_direction(DATA_DIRECTION_WRITE);

  for (int i = 7; i >= 0; i--) {
    digitalWrite(SBC_DATA[i], value & 1);
    value = value >> 1;
  }

  digitalWrite(SBC_RW, LOW);
  delayMicroseconds(1);
  digitalWrite(SBC_RW, HIGH);
}

/* 
 * Have a peek at the specified memory address, but will return a blank
 * value with all bits set if we were not able to access the bus.
 */
byte peek(const unsigned long address) {
  set_address(address);
  return read_byte();
}

/*
 * Poke a byte into memory at the specified address, but not that no
 * checking will be done so make sure that the value returned is the same
 * you gave us in the first place!
 */
byte poke(const unsigned long address, byte value) {
  set_address(address);
  write_byte(value, true);
  return read_byte();
}

void zero_memory(const unsigned int start_address, const unsigned int end_address, byte value = 0x00) {
  unsigned int num_bytes = 0;
  unsigned int base = start_address;
  set_data_direction(DATA_DIRECTION_WRITE);
  while (base <= end_address) {
    set_address(base);
    write_byte(value, false);
    base++;
    num_bytes++;
  }
  set_data_direction(DATA_DIRECTION_READ);
  ansi_notice();
  Serial.print(num_bytes);
  Serial.println(F(" bytes written."));
  ansi_default();
}
void zero_zp() { zero_memory(0x0000, 0x00ff); }
void zero_stack() { zero_memory(0x0100, 0x01ff); }
void zero_ram() { zero_memory(0x0000, 0x3fff); }
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

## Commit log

2019-11-04 Schematic done
    [BE6502 SBC.kicad_pcb, BE6502 SBC.sch]
2019-11-04 Added LEDs
    [BE6502 SBC.sch]
2019-11-04 Component placement
    [BE6502 SBC.kicad_pcb, BE6502 SBC.sch]
2019-11-07 Layout done
    [BE6502 SBC.kicad_pcb, BE6502 SBC.sch]
2019-11-13 Added PCB preview
2019-11-13 Added README and TODO
    [BE6502 SBC-B.Cu.gbl, BE6502 SBC-B.Mask.gbs, BE6502 SBC-B.Paste.gbp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]
2019-11-16 Added clock module
    [BE6502 Clock-B.Cu.gbl, BE6502 Clock-B.Mask.gbs, BE6502 Clock-B.Paste.gbp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]
2019-11-16 Updated gerbers for CPU
    [BE6502 SBC-B.Cu.gbl, BE6502 SBC-B.Mask.gbs, BE6502 SBC-B.Paste.gbp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]
2019-11-17 Arduino bus monitor layout
    [BE6502 Mega Adapter.kicad_pcb, BE6502 Mega Adapter.sch]
2019-11-17 Mega Adapter gerber export
    [BE6502 Mega Adapter-B.Cu.gbl, BE6502 Mega Adapter-B.Mask.gbs, BE6502 Mega Adapter-B.Paste.gbp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]
2019-11-27 Copied Ben Eaters Arduino sketch
2019-11-27 Arduino monitor description
2019-11-27 Adjusted clock module after building
    [BE6502 Clock-B.Cu.gbl, BE6502 Clock-B.Mask.gbs, BE6502 Clock-B.Paste.gbp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]
2019-11-28 Adjusted SBC silkscreen
    [BE6502 Clock-B.Cu.gbl, BE6502 Clock-B.Mask.gbs, BE6502 Clock-B.Paste.gbp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]
2019-11-28 Updated Mega shield silkscreen
    [BE6502 Mega Adapter-B.Cu.gbl, BE6502 Mega Adapter-B.Mask.gbs, BE6502 Mega Adapter-B.Paste.gbp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]
2019-11-28 Updated backplane silkscreen
    [BE6502 Mega Adapter-B.Cu.gbl, BE6502 Mega Adapter-B.Mask.gbs, BE6502 Mega Adapter-B.Paste.gbp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]
2019-11-28 Arduino-module README added
2019-12-07 Example 002 and 003, currently untested and probably full of bugs
    [debounce.asm, echo.asm]
2019-12-12 Character UP/DOWN with mode switch (untested)
2019-12-13 Fixed DOWN in MODE=1
    [namebadge.asm]
2019-12-13 UP/DOWN now count correctly
    [namebadge.asm]
2019-12-14 Clear first RAM byte, MODE correctly set on sideways move.
    [namebadge.asm]
2019-12-14 Added memory map
    [memory_map.ods]
2020-01-18 Added some switches and an LED to unused pins
    [BE6502 Mega Adapter-B.Cu.gbl, BE6502 Mega Adapter-B.Mask.gbs, BE6502 Mega Adapter-B.Paste.gbp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]
2020-02-13 Updated Mega Adapter to Kicad 5
    [BE6502 Mega Adapter-2020-02-13-12-58-30.sch]
2020-02-13 Switch debouncing
2020-02-14 Fixed sketch compilation error
    [commands.cpp, constants.h]
2020-02-14 Updated clock with capacitor from video 3
    [BE6502 Clock-B.Cu.gbl, BE6502 Clock-B.Mask.gbs, BE6502 Clock-B.Paste.gbp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]
2020-02-14 Tweaks to schematic
2020-02-15 Added BE pin to backplane
    [BE6502 SBC-2020-02-15-17-16-45.sch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]
2020-02-15 Attempt to use timer3 as clock (untested)
2020-02-16 Tweaked Arduino clock functions
2020-02-17 Cosmetic schematic tweak
    [BE6502 SBC.sch]
2020-02-18 Added current limiting resistor in case more than one clock accidentally activated at the same time
    [BE6502 SBC.kicad_pcb, BE6502 SBC.sch]
2020-02-18 Moved arduino clock and reset functions into separate file
    [clock.cpp, commands.cpp]
2020-02-20 Proxy switch actions through commands
2020-02-21 Bus control issue fixed due to wrong sequence
    [6502-monitor.ino, bus_control.cpp, commands.cpp]
2020-02-21 Shorten down code by using new formatting
    [ansi.cpp, ansi.h, bus_control.cpp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]
2020-02-21 Type in memory map
    [memory_map.ods]
2020-02-23 Arduino README tweaked
2020-03-11 Revised SBC to add reset circuit
    [BE6502 SBC-B.Cu.gbl, BE6502 SBC-B.Mask.gbs, BE6502 SBC-B.Paste.gbp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]
2021-11-30 Fixed issue with clock module
    [BE6502 Clock-2021-11-30-19-32-30.sch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]
2021-11-30 Update errata and bump module revision number
    [BE6502 Clock-B_Cu.gbl, BE6502 Clock-B_Mask.gbs, BE6502 Clock-B_Paste.gbp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]
